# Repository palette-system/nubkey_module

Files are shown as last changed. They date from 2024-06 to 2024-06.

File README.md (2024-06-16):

# nubkey_module
Nubkey をPIM447と同じ通信で使用できるようにしたモジュールです。

<br><br>

<table>
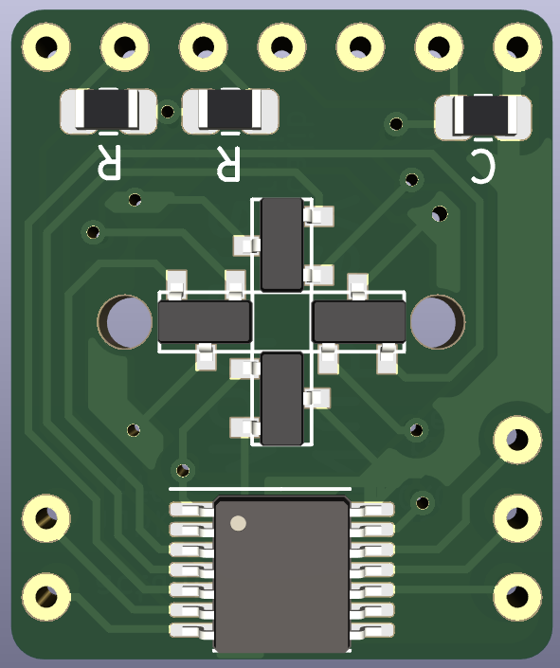
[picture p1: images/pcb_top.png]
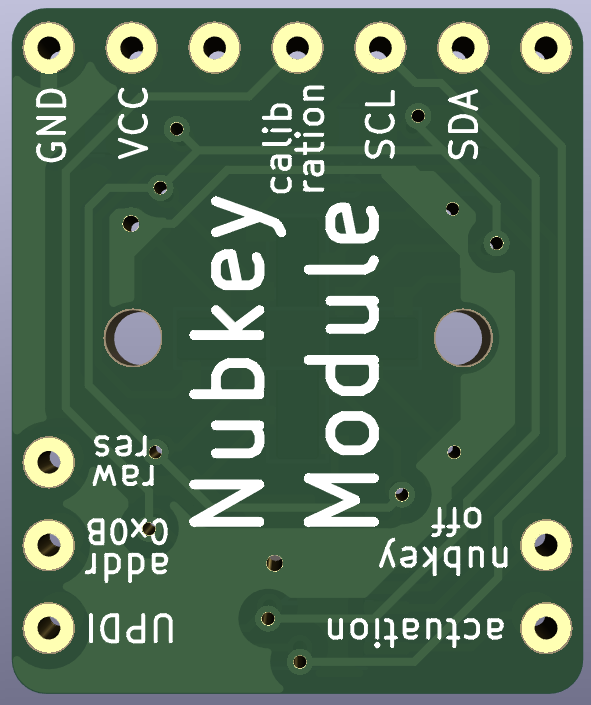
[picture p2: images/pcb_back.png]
<tr><td></td><td></td></tr>
</table>

<br><br>

## ドキュメント

<a href="/docs/structure.md">nubkey_module　基礎知識</a><br>
nubkey_modul を使用するにあたり作成者も、設計者も一度確認してからご使用ください。<br>
<br>

<a href="/docs/module_build.md">nubkey_module　はんだ付け手順</a><br>
nubkey_module をPCBにはんだ付けする際にご確認下さい。<br>
<br>

<a href="/docs/tester_build.md">nubkey_module tester　ビルドガイド</a><br>
nubkey_module tester を組み立てる際にご確認下さい。<br>
<br>

<a href="https://palette-system.github.io/nubkey_module/">nubkey_module tester　ファームウェア書き込み</a><br>
nubkey_module tester を使用する際にご確認下さい。<br>
<br>

<a href="/docs/command.md">nubkey_module　通信仕様</a><br>
nubkey_module で実行できるI2Cのコマンドの仕様書です。QMK等から速度調節する場合等にご確認下さい。<br>
<br>

<a href="/hardware/nubkey_module_tester/">nubkey_module tester　KiCadデータ</a><br>
nubkey_module tester のKiCadデータです。nubkey_module を使用したキーボードを作る際の参考にして下さい。<br>
<br>
<br>

## 基本的な接続
<br>
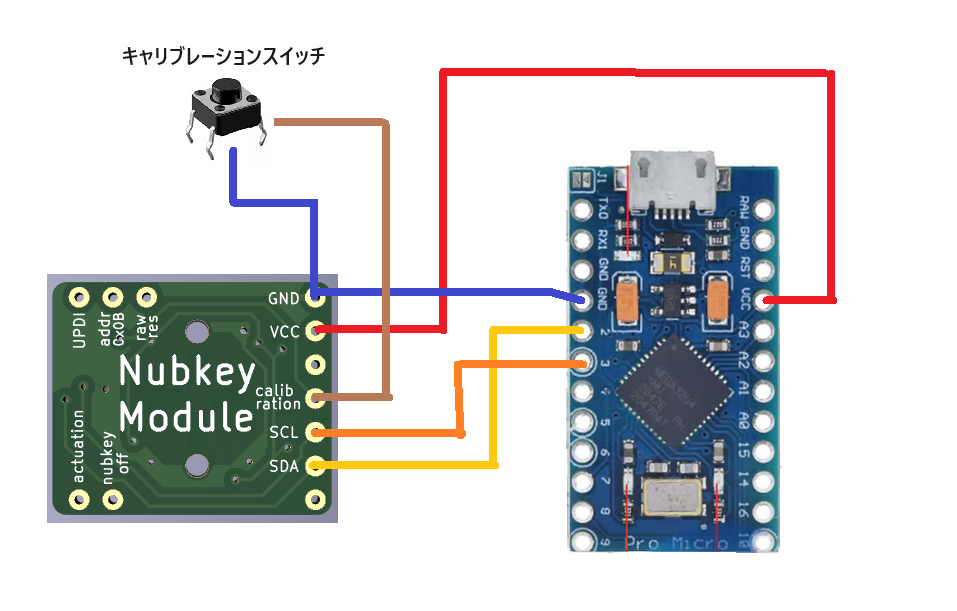
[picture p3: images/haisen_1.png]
<br>
<br>

## キャリブレーション
どんなに気を付けて作成しても組み立て毎に磁気スイッチの中心位置が0.数ミリズレが生じます。<br>
キャリブレーションスイッチを押したまま、Nubkeyを押下して上下左右にグリグリ動かす事で nubkey_module のソフト側で中心位置を調節できます。<br>
<br>

## オススメの構造
<br>
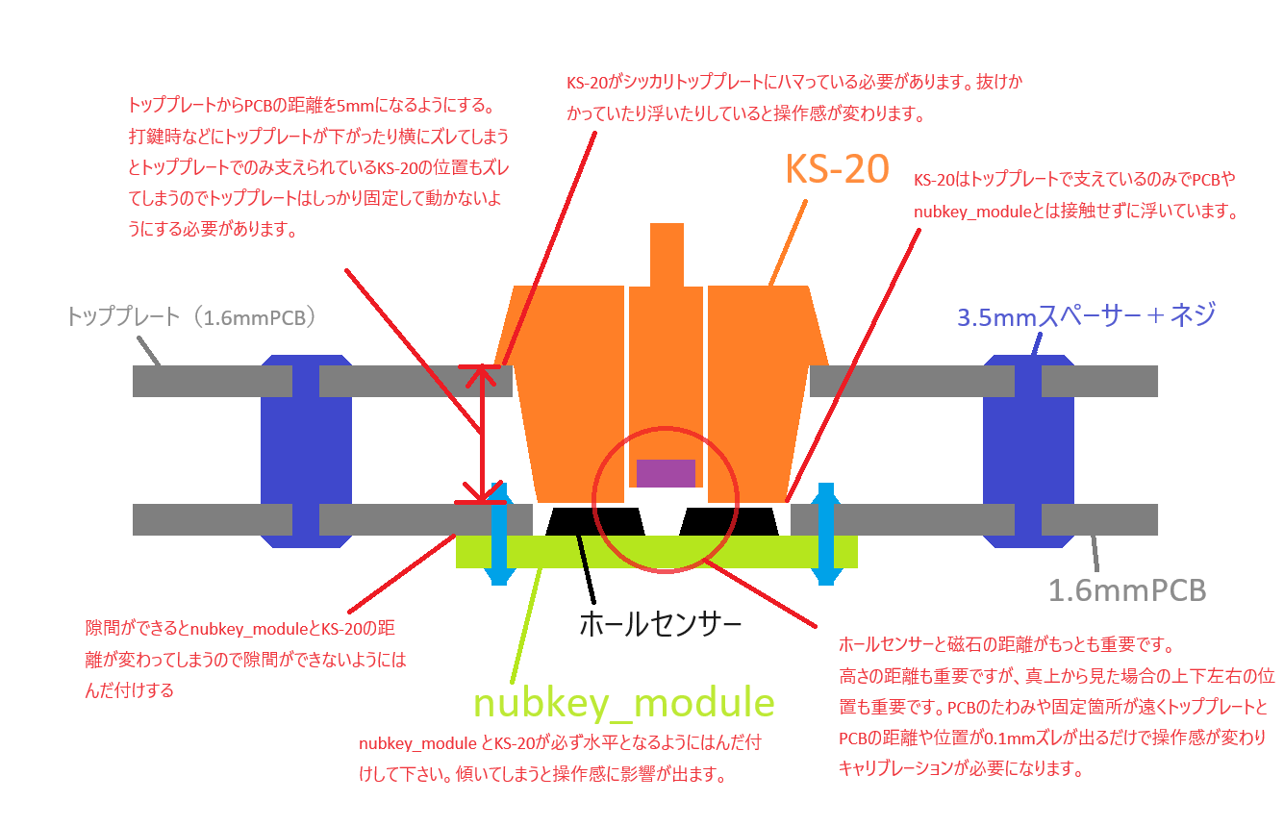
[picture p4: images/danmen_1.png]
<br>
<br>

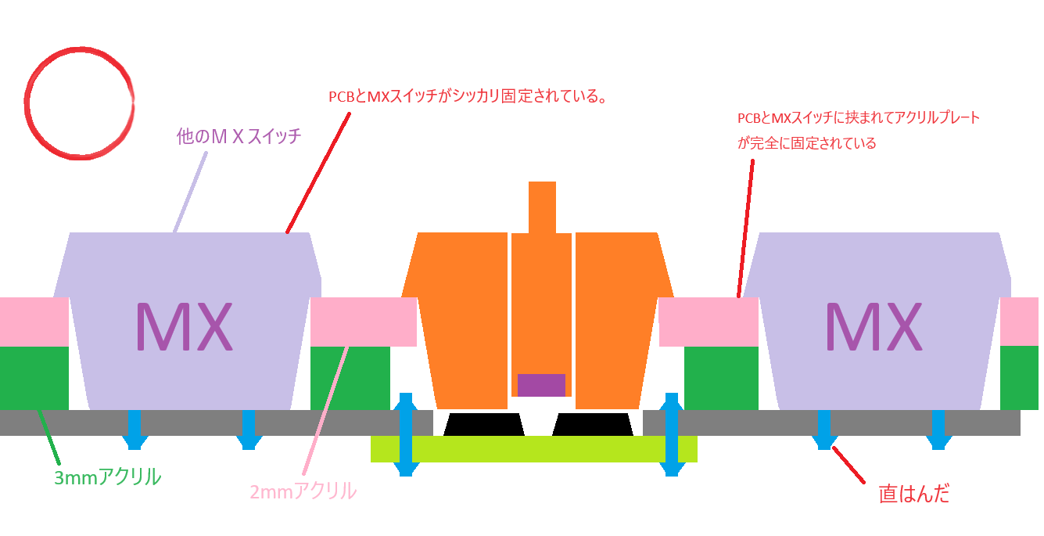
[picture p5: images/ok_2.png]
<br>
<br>

## ピンの説明

|  ピン  |  説明  |
|  ----  |  :---  |
|  UPDI  |  nubkey_module のファームを更新するためのピンです  |
|  addr 0x0B  |  nubkey_module のI2Cアドレスを0x0Bにするピンです。<br>このピンをGNDに接続した状態で起動するとI2Cアドレスが0x0Bになります。  |
|  raw res  |  I2CのレスポンスがデフォルトではPIM447互換ですがこのピンをGNDに接続すると「short X座標, short Y座標, short スイッチの押し込み具合」を返すようになります。  |
|  actuation  |  アクチュエーションポイント設定ピンです。このピンをGNDに接続するとアクチュエーション設定モードに入ります。その後GNDへの接続を切断したタイミングのKS-20のスイッチの高さがアクチュエーションポイントとしてnubkey_moduleに保存されます。  |
|  nubkey off  |  このピンをGNDに接続すると、マウス移動が無しの状態になりスイッチのON/OFFのみが変わるようになります。この時actuationピンで設定したスイッチの高さでON/OFFが切り替わります。  |
|  GND  |  GNDです  |
|  VCC  |  電源です。3.3Vを接続して下さい。  |
|  SCL  |  I2C通信用（SCL）  |
|  SDA  |  I2C通信用（SDA）  |
|  calibration  |  キャリブレーションピンです。このピンをGNDに接続した状態でKS-20のスイッチを押してグリグリすると、Nubkeyの中心位置を調節できます。<br>キャリブレーションの結果は nubkey_module に保存されるので起動のたびキャリブレーションを行う必要はありません。  |

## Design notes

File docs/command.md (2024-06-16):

# nubkey_module　通信仕様

<br>
nubkey_module は AZ1UBALL 同様にPIM447と同じ通信でQMKなどから使用できます。<br>

<br><br>

## デフォルトのレスポンスフォーマット　(PIM447互換)
<br>

|  内容  |  説明  |  サイズ(byte)  |
|  --  |  --  |  --  |
|  移動距離  |  左方向への移動距離  |  1  |
|  移動距離  |  右方向への移動距離  |  1  |
|  移動距離  |  上方向への移動距離  |  1  |
|  移動距離  |  下方向への移動距離  |  1  |
|  スイッチ  |  0x00 = ボタン OFF<br>0x80 = ボタン ON  |  1  |

<br><br>

## QMK起動時にコマンドを実行する例
<br>
通常のレスポンスとは別にI2Cでコマンドを送信する事で細かい設定を行う事ができます。<br>
<br>

```
void pointing_device_init_kb(void) {
    // _delay_ms(100); // nubkey_module の起動よりもProMicroの起動のが早い場合用 nubkey_module の起動を待ってから設定コマンドを投げる
    uint8_t res[8];
    uint16_t timeout=100;
    i2c_status_t status;
    uint8_t addr=0x0A << 1;
    // 送信するコマンド
    uint8_t cmd[]={0x48,   /* 左 */ 0x03, 0xE8,   /* 右 */ 0x03, 0xE8,   /* 上 */ 0x03, 0xE8,   /* 下 */ 0x03, 0xE8}; // マウス移動の速度 左右上下
    // uint8_t cmd[]={0x47, 0x01, 0x68}; // 高さ調節
    // uint8_t cmd[]={0x4A}; // 設定リセット
    // コマンドの送信
    status  = i2c_transmit(addr, cmd, sizeof(cmd), timeout);
    if (status != 0) return;
    status = i2c_receive(addr, res, 1, timeout);
}
```

<br><br>

# I2C コマンド一覧

## 0x60　製品の情報取得

<b>■ 送信 ： 1 byte </b>
|  内容  |  説明  |  サイズ(byte)  |
|  --  |  --  |  --  |
|  コマンドタイプ  |  0x60 (固定)  |  1  |

<b>■ レスポンス ： 4 byte </b>
|  内容  |  説明  |  サイズ(byte)  |
|  --  |  --  |  --  |
|  コマンドのエコー  |  0x60（固定）  |  1  |
|  I2Cアドレス  |  nubkey_moduleのI2Cアドレス  |  1  |
|  製品番号  |  nubkey_moduleの識別番号（0x20 固定）  |  1  |
|  ファームウェアバージョン  |  使用されているファームウェアのバージョン  |  1  |

<br><br>

## 0x40　I2Cアドレスを変更する
nubkey_moduleのI2Cアドレスを変更して、nubkey_moduleを再起動します。<br>
<b>■ 送信 ： 2 byte </b>
|  内容  |  説明  |  サイズ(byte)  |
|  --  |  --  |  --  |
|  コマンドタイプ  |  0x40 (固定)  |  1  |
|  I2Cアドレス  |  変更後のI2Cアドレス<br>0x00 を指定した場合デフォルトの0x0A（0x0BピンがGNDに接続されていた場合0x0B）になります。<br>（デフォルト：　0x00）  |  1  |

<b>■ レスポンス ： 1 byte </b>
|  内容  |  説明  |  サイズ(byte)  |
|  --  |  --  |  --  |
|  コマンドのエコー  |  0x40（固定）  |  1  |

<br><br>

## 0x41　設定内容を取得する

<b>■ 送信 ： 1 byte </b>
|  内容  |  説明  |  サイズ(byte)  |
|  --  |  --  |  --  |
|  コマンドタイプ  |  0x41 (固定)  |  1  |

<b>■ レスポンス ： 23 byte </b>
|  内容  |  説明  |  サイズ(byte)  |
|  --  |  --  |  --  |
|  コマンドのエコー  |  0x41  |  1  |
|  I2Cアドレス  |  nubkey_moduleのI2Cアドレス  |  1  |
|  nubkey_off_status  |  Nubkey_offにするかどうか<br>(0=Nubkey OFF / 1=Nubkey ON / 2=ピンの情報優先)  |  1  |
|  key_actuation  |  Nubkey_off時のアクチュエーションポイント  |  2  |
|  nub_start_time  |  Nubkeyとしてマウス操作させるまでの時間(ミリ秒)  |  2  |
|  nub_start_down  |  Nubkey マウス移動開始させるアクチュエーションポイント  |  2  |
|  nub_speed_left  |  Nubkey マウス移動させる速度 左  |  2  |
|  nub_speed_right  |  Nubkey マウス移動させる速度 右  |  2  |
|  nub_speed_up  |  Nubkey マウス移動させる速度 上  |  2  |
|  nub_speed_down  |  Nubkey マウス移動させる速度 下  |  2  |
|  rang_x  |  キャリブレーション中心の X 座標  |  2  |
|  rang_y  |  キャリブレーション中心の Y 座標  |  2  |
|  loop_delay  |  入力読み込みサイクルのdelay値(ミリ秒)  |  2  |

<br><br>

## 0x42　Nubkey OFF モードの設定
Nubkey OFF モードを設定して EEPROM に保存します。<br>
<b>■ 送信 ： 2 byte </b>
|  内容  |  説明  |  サイズ(byte)  |
|  --  |  --  |  --  |
|  コマンドタイプ  |  0x42 (固定)  |  1  |
|  モード  |  0=NubkeyOFFモード OFF<br>1=NubkeyOFFモード ON<br>2=ピンの情報優先（デフォルト）  |  1  |

<b>■ レスポンス ： 1 byte </b>
|  内容  |  説明  |  サイズ(byte)  |
|  --  |  --  |  --  |
|  コマンドのエコー  |  0x42  |  1  |

<br><br>

## 0x43　アクチュエーション設定モードの設定
アクチュエーション設定モードの設定。<br>
このコマンドを投げるのとactuationピンをGNDに接続するのと同等の制御ができます。<br>
<b>■ 送信 ： 2 byte </b>
|  内容  |  説明  |  サイズ(byte)  |
|  --  |  --  |  --  |
|  コマンドタイプ  |  0x43 (固定)  |  1  |
|  モード  |  0=アクチュエーション設定モード OFF<br>1=アクチュエーション設定モード ON<br>2=ピンの情報優先(デフォルト)  |  1  |

<b>■ レスポンス ： 1 byte </b>
|  内容  |  説明  |  サイズ(byte)  |
|  --  |  --  |  --  |
|  コマンドのエコー  |  0x43  |  1  |

<br><br>

## 0x44　キャリブレーション設定モードの設定
キャリブレーション設定モードの設定。<br>
このコマンドを投げるのとcalibrationピンをGNDに接続するのと同等の制御ができます。<br>
<b>■ 送信 ： 2 byte </b>
|  内容  |  説明  |  サイズ(byte)  |
|  --  |  --  |  --  |
|  コマンドタイプ  |  0x44 (固定)  |  1  |
|  モード  |  0=キャリブレーション設定モード OFF<br>1=キャリブレーション設定モード ON<br>2=ピンの情報優先(デフォルト)  |  1  |

<b>■ レスポンス ： 1 byte </b>
|  内容  |  説明  |  サイズ(byte)  |
|  --  |  --  |  --  |
|  コマンドのエコー  |  0x44  |  1  |

<br><br>

## 0x45　アクチュエーションポイント設定
アクチュエーションポイント設定してEEPROMに保存します。<br>
※ このアクチュエーションポイントは Nubkey OFF モードの時に使用されます。<br>
<b>■ 送信 ： 3 byte </b>
|  内容  |  説明  |  サイズ(byte)  |
|  --  |  --  |  --  |
|  コマンドタイプ  |  0x45 (固定)  |  1  |
|  アクチュエーションポイント  |  キーをONにする高さを指定<br>ここで指定した高さを下回るとキーがONになります。<br>（デフォルト：　280）  |  2  |

<b>■ レスポンス ： 1 byte </b>
|  内容  |  説明  |  サイズ(byte)  |
|  --  |  --  |  --  |
|  コマンドのエコー  |  0x45  |  1  |

<br><br>

## 0x46　Nubkey 開始までの時間を設定
Nubkeyとしてマウス操作させるまでの時間を更新してEEPROMに保存します。<br>
ここで指定した時間より短い時間でキーを離すと、タップ判定となりキーONが送信されます。<br>
<b>■ 送信 ： 2 byte </b>
|  内容  |  説明  |  サイズ(byte)  |
|  --  |  --  |  --  |
|  コマンドタイプ  |  0x46 (固定)  |  1  |
|  時間  |  Nubkey 開始までの時間（ミリ秒）（デフォルト：　200）  |  2  |

<b>■ レスポンス ： 1 byte </b>
|  内容  |  説明  |  サイズ(byte)  |
|  --  |  --  |  --  |
|  コマンドのエコー  |  0x46  |  1  |

<br><br>

## 0x47　Nubkey を動かし始める高さを設定
Nubkey 動かし始める高さを変更してEEPROMに保存します。<br>
<b>■ 送信 ： 3 byte </b>
|  内容  |  説明  |  サイズ(byte)  |
|  --  |  --  |  --  |
|  コマンドタイプ  |  0x47 (固定)  |  1  |
|  高さ  |  200～400　（デフォルト：　360）  |  2  |

<b>■ レスポンス ： 1 byte </b>
|  内容  |  説明  |  サイズ(byte)  |
|  --  |  --  |  --  |
|  コマンドのエコー  |  0x47  |  1  |

<br><br>

## 0x48　Nubkey マウス移動の速度設定
Nubkeyとしてマウス操作させる速度を更新してEEPROMに保存します。<br>
数値が小さいほど早く動きます。<br>
<b>■ 送信 ： 9 byte </b>
|  内容  |  説明  |  サイズ(byte)  |
|  --  |  --  |  --  |
|  コマンドタイプ  |  0x48 (固定)  |  1  |
|  移動速度 左  |  移動速度　(デフォルト：　800)  |  2  |
|  移動速度 右  |  移動速度　(デフォルト：　800)  |  2  |
|  移動速度 上  |  移動速度　(デフォルト：　600)  |  2  |
|  移動速度 下  |  移動速度　(デフォルト：　600)  |  2  |

<b>■ レスポンス ： 1 byte </b>
|  内容  |  説明  |  サイズ(byte)  |
|  --  |  --  |  --  |
|  コマンドのエコー  |  0x48  |  1  |

<br><br>

## 0x49　Nubkey 読み込みサイクルのdelay値設定
Nubkey 読み込みサイクルのdelay値を変更してEEPROMに保存します。<br>
<b>■ 送信 ： 3 byte </b>
|  内容  |  説明  |  サイズ(byte)  |
|  --  |  --  |  --  |
|  コマンドタイプ  |  0x49 (固定)  |  1  |
|  時間  |  停止する時間（ミリ秒）（デフォルト 2）  |  2  |

<b>■ レスポンス ： 1 byte </b>
|  内容  |  説明  |  サイズ(byte)  |
|  --  |  --  |  --  |
|  コマンドのエコー  |  0x49  |  1  |

<br><br>

## 0x4A　設定を全てリセットして再起動
<b>■ 送信 ： 1 byte </b>
|  内容  |  説明  |  サイズ(byte)  |
|  --  |  --  |  --  |
|  コマンドタイプ  |  0x4A (固定)  |  1  |

<b>■ レスポンス ： 1 byte </b>
|  内容  |  説明  |  サイズ(byte)  |
|  --  |  --  |  --  |
|  コマンドのエコー  |  0x4A  |  1  |

<br><br>

## 0x50　Nubkey のアナログ情報を取得
<b>■ 送信 ： 1 byte </b>
|  内容  |  説明  |  サイズ(byte)  |
|  --  |  --  |  --  |
|  コマンドタイプ  |  0x50 (固定)  |  1  |

<b>■ レスポンス ： 7 byte </b>
|  内容  |  説明  |  サイズ(byte)  |
|  --  |  --  |  --  |
|  コマンドのエコー  |  0x50  |  1  |
|  X座標  |  Nubkey の現在のX座標  |  2  |
|  Y座標  |  Nubkey の現在のY座標  |  2  |
|  高さ  |  キーの押し込み現在の高さ  |  2  |

<br><br>

## 0x51　ホールセンサーの情報を取得
<b>■ 送信 ： 1 byte </b>
|  内容  |  説明  |  サイズ(byte)  |
|  --  |  --  |  --  |
|  コマンドタイプ  |  0x51 (固定)  |  1  |

<b>■ レスポンス ： 9 byte </b>
|  内容  |  説明  |  サイズ(byte)  |
|  --  |  --  |  --  |
|  コマンドのエコー  |  0x51  |  1  |
|  アナログ値  |  ホールセンサーのアナログ値 上  |  2  |
|  アナログ値  |  ホールセンサーのアナログ値 下  |  2  |
|  アナログ値  |  ホールセンサーのアナログ値 左  |  2  |
|  アナログ値  |  ホールセンサーのアナログ値 右  |  2  |

<br><br>

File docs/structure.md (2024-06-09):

# nubkey_module　を使用する上での基礎知識
<br><br>
nubkey_module を使用したキーボードを作成する人も設計する人もどういう仕組みで動いている物なのか確認してからのご使用をお願いします。<br>
とても繊細な仕組みの元成り立っている技術なので、設計の仕方、組み立て方次第で操作感に影響が出ます。<br>
<br><br>

## 構造の説明
<br>

pcb

<br>

### KS-20とホールセンサーの位置が最も重要
KS-20の中心位置と十字に並ぶホールセンサーの中心の位置がピッタリ合っているほど操作しやすくなります。<br>
位置が0.1mmズレるだけで特定の方向にだけにマウス移動する速度が遅くなったり、ひどい場合はマウスが勝手に移動してしまうなどの現象が起こります。<br>
多少であればキャリブレーションを行う事で調節できますが、使っているウチに振動でトッププレートが沈んだり、たわみでKS-20の位置とホールセンサーの位置がズレたりすると定期的にキャリブレーションを行わなければならず不便な物になってしまいます。<br>

<br><br>

### KS-20 は浮いています
NubkeyとなるKS-20はトッププレートに支えられているのみで浮いています。<br>
通常の電気接点のあるMXスイッチであれば多少ソケットから抜けたり斜めに刺さってしまっても動作しますが、Nubkeyはマウスの操作に影響が出てしまいます。<br>
なので 「KS-20→トッププレート→PCB→nubkey_module」 までの間がシッカリ固定されて動かないようになっている必要があります。<br>

<br><br>

### nubkey_module のはんだづけ
PCBに nubkey_module をはんだ付けする際はシッカリとPCBと密着して隙間が無い状態にして下さい。<br>
ここで隙間ができるとKS-20と水平にならなくなってしまい操作感に影響が出る可能性があります。<br>

<br><br>
<br><br>

## キャリブレーションについて
<br>

### 磁石の中心位置
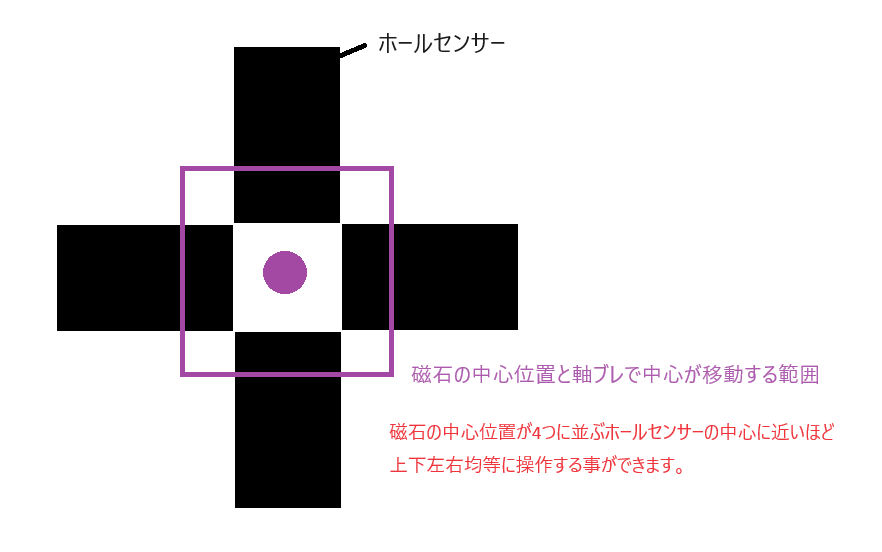
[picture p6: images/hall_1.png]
<br>
<br>
磁石の中心位置が最も磁力線が強くなっていて、この位置が上下左右に動いた事をホールセンサーで感知してマウスを上下左右に動かしています。<br>
KS-20の軸ブレで移動する範囲が丁度十字に並んだホールセンサーの中心にあるとどの方向に移動しても均一に移動を感知できるので、操作感が良くなります。<br>
<br>

### 中心位置がズレると何が起こるか
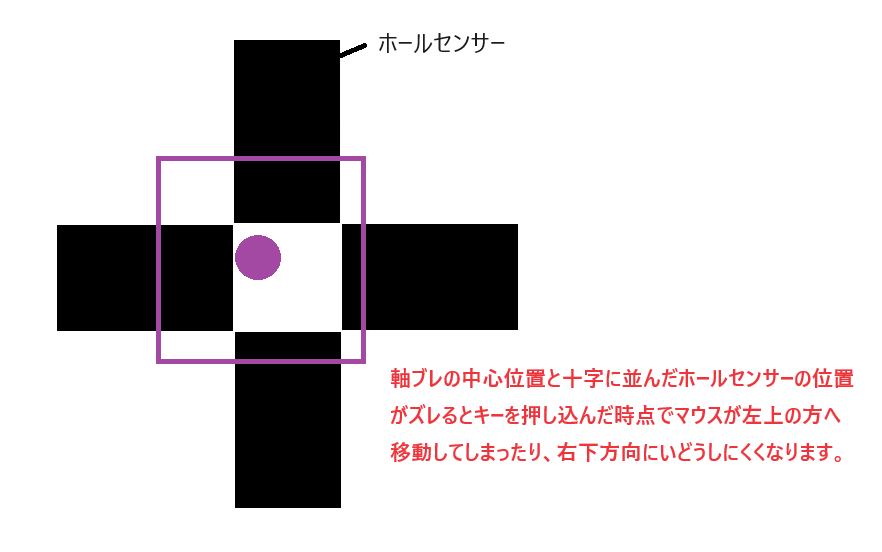
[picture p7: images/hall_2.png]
<br>
<br>
KS-20の軸ブレの中心位置がズレると、十字に並んだホールセンサー上での移動できる範囲が変わります。<br>
デフォルトのままだと十字の中心位置がNubkeyの中心と設定してあるので、キーを押しただけで左上の方へマウス移動してしまい操作感が悪くなります。<br>
<br>

### キャリブレーション
0.1mmのズレで操作感が変わってしまうので、例えばトッププレートを外してもう一度付け直しただけでネジ穴の遊び(隙間)分KS-20の中心位置が移動したりします。<br>
なのでキャリブレーションボタンを押したままKS-20をグリグリする事で、現在軸ブレはどの範囲まで移動できるかをnubkey_moduleに確認させる事ができます。<br>
そうする事で軸ブレの中心位置を設定し、マウスが特定方向にだけ動きにくくなる事を修正できます。<br>
<br>

### キャリブレーションは完璧ではない
中心位置の調整はキャリブレーションで行えるのですが、軸ブレの中心位置がズレていた場合に特定の方向のホールセンサーからの距離が遠くなってしまうと、その方向への数値の取得が小さくなります。<br>
例えば左に行く時はちょっと倒すとゆっくり動く、いっぱい倒すと早く動くの調節が利くけど、右に倒す時はちょっと倒しただけで早く動いてしまうなどの現象が起こります。<br>
nubkey_moduleに特定のI2Cコマンドを投げる事で上下左右の移動速度を設定できるようにして、ある程度は調節できるようにしてありますが都度調節はなかなか難しいので設計時、組み立てる時にnubkey_moduleやプレートにズレが発生しない様に気を付けて下さい。<br>

<br><br>
<br><br>

## トッププレートとPCBの固定方法
<br>
上記で説明してきた通りトッププレートとPCBがシッカリ固定されている事が快適にNubkeyを操作するにあたってとても重要です。<br>
固定方法について良かったパターン悪かったパターンを紹介します。<br>
まだいろいろな方法を試せていないというのが現状なのでいろいろな構造を試して頂けたらなと思います。<br>
<br>

<table>
<tr>
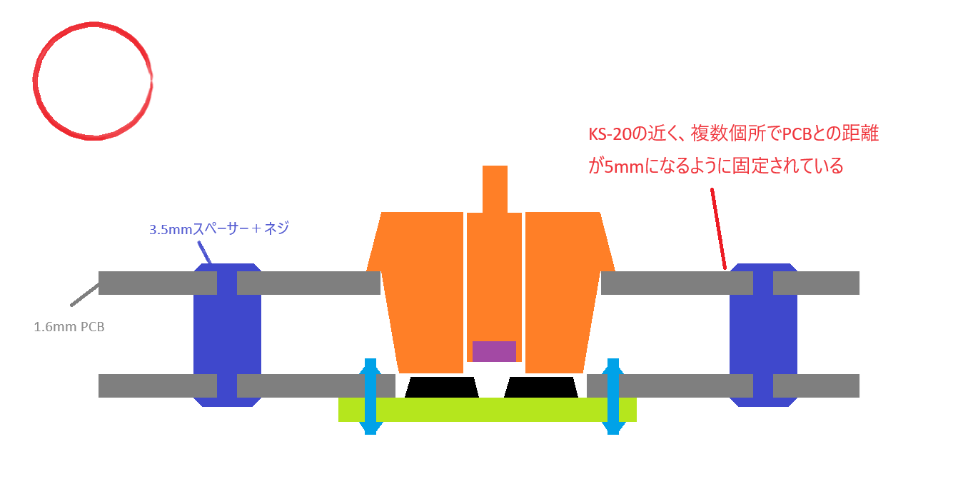
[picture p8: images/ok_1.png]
<td></td>
<td>
<b>トッププレートとPCBをスペーサーで固定する</b><br>
かなり確実なパターンで、スペーサーで固定しているのでズレが発生してもネジを外してトッププレートを付け直す事で調整できます。<br>
ただネジで止める箇所が遠かったり、止める数が少なかったりした場合他のMXスイッチのせいで高さに隙間ができたり、PCBのたわみで位置ズレ高さズレが発生する可能性があるので、Nubkeyの近く数か所で固定するのが良さそうです。<br>
長く使用した場合にネジのゆるみなどで固定が甘くならないかの心配は少しあります。
</td>
</tr>
<tr>
<td></td>
<td>
<b>2mm＋3mmトッププレートで、他のMXスイッチは直はんだ</b><br>
一番確実なパターンで、5mmのプレートを他のMXスイッチで挟んでPCBに完全に固定します。<br>
なので使用するにあたって一度位置調整すれば位置ズレが発生する事がありません。
</td>
</tr>
<tr>
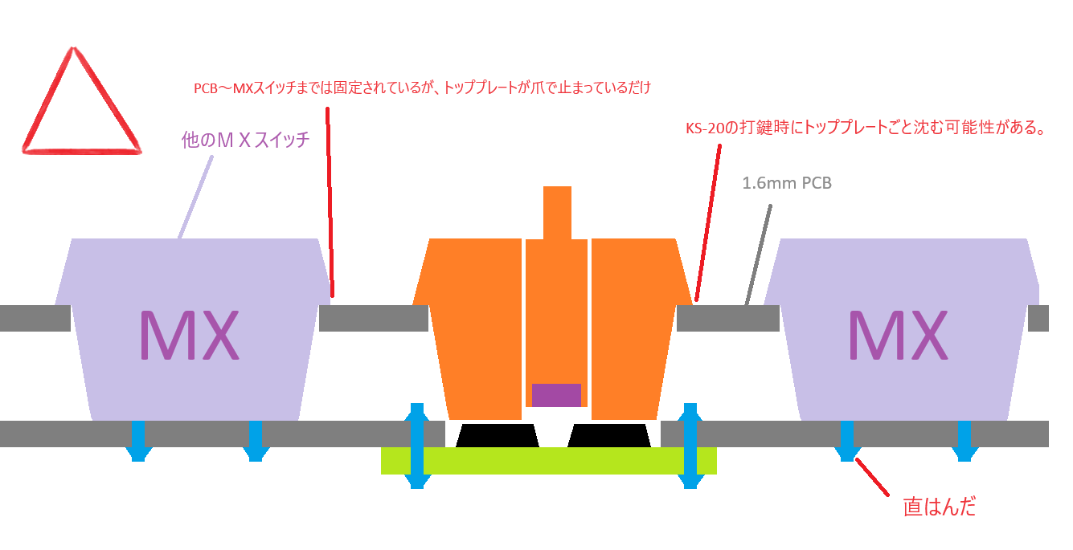
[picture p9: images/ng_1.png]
<td></td>
<td>
<b>トッププレートが浮いているパターン</b><br>
トッププレートがMXスイッチの爪で固定されているだけなので、使用している間に爪が外れやすくなったりPCBのたわみで位置ズレが発生する可能性があります。<br>
ただし全く使えないというわけでは無いので定期的にキャリブレーションや速度調整をする前提であれば一度試してみるのはありだと思います。<br>
</td>
</tr>
<tr>
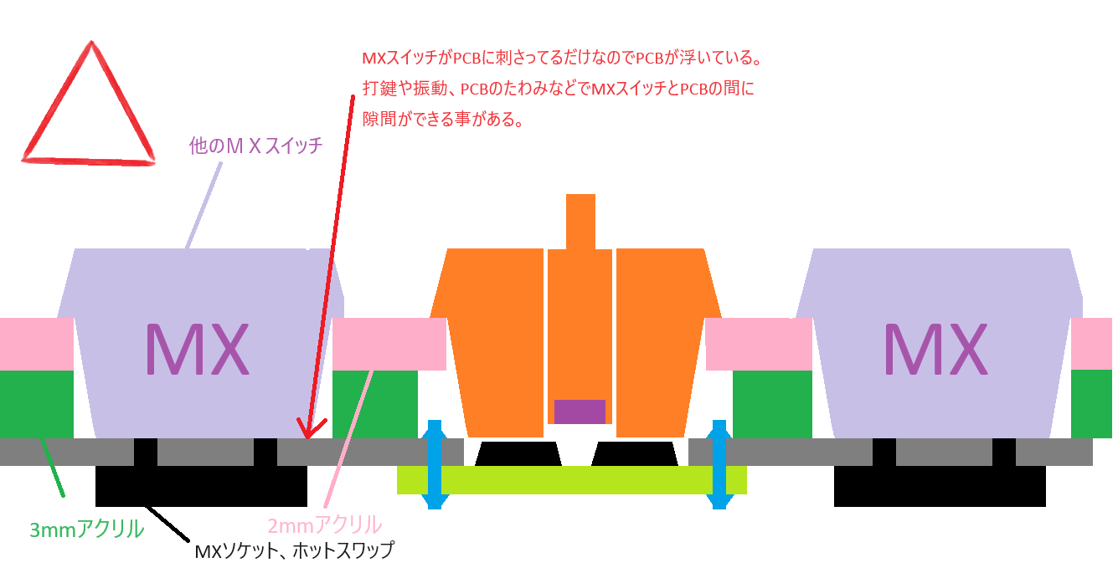
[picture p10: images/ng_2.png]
<td></td>
<td>
<b>PCBがホットスワップで支えられてるだけで浮いてる</b><br>
ホットスワップは使用しているウチに抜けたり浮いたりし易いので、この構造だと位置ズレが発生する可能性があります。<br>
どこかでトッププレートからPCBまでネジなどで固定できると良いかもしれません。（アクリルもPCBもたわみが発生するので近くで数か所が望ましいです）
</td>
</tr>
</table>

<br><br>

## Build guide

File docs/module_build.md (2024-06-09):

# nubkey_module　のはんだ付け
<br><br>
nubkey_module は PCB に隙間なくピッタリとくっついた状態ではんだ付けする必要があります。<br>
手順を確認しながらはんだ付けして下さい。<br>
<br><br>

## 細ピンヘッダをカットします
<br>
ピンに合わせて細ピンヘッダをカットしてください。<br>
<br>
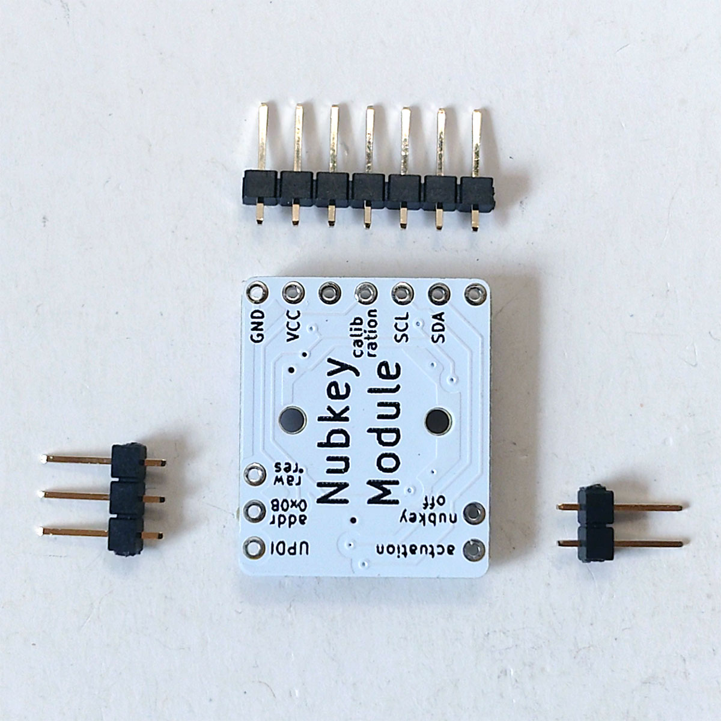
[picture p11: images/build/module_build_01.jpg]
<br>

<br><br>

## PCB の裏面に nubkey_module の乗せます
<br>
PCB の裏面に nubkey_module の乗せて細ピンヘッダを刺して下さい。<br>
<br>
<table><tr>
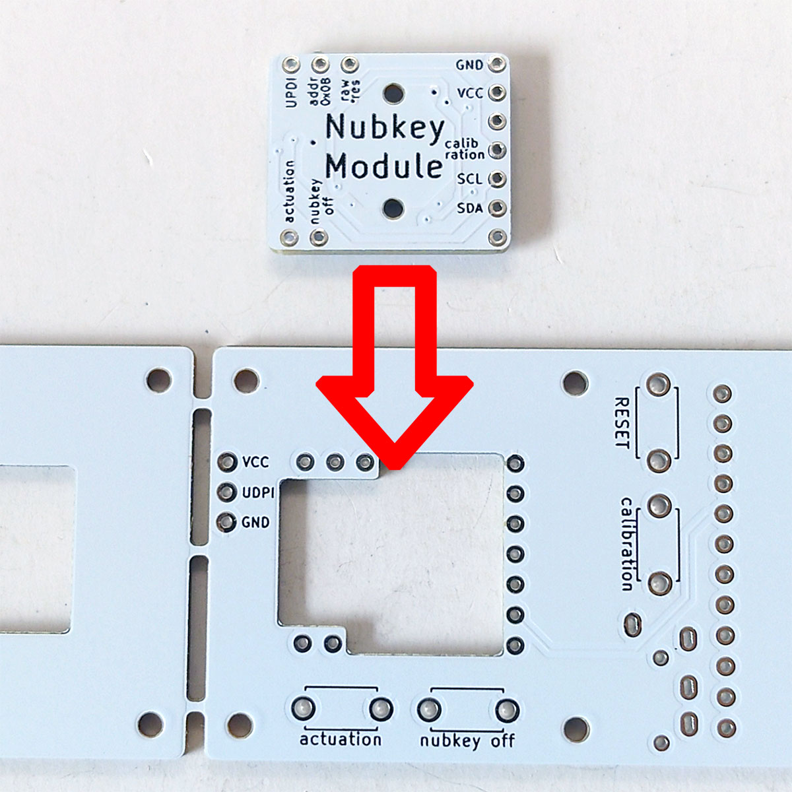
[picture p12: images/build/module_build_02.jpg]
<td></td>
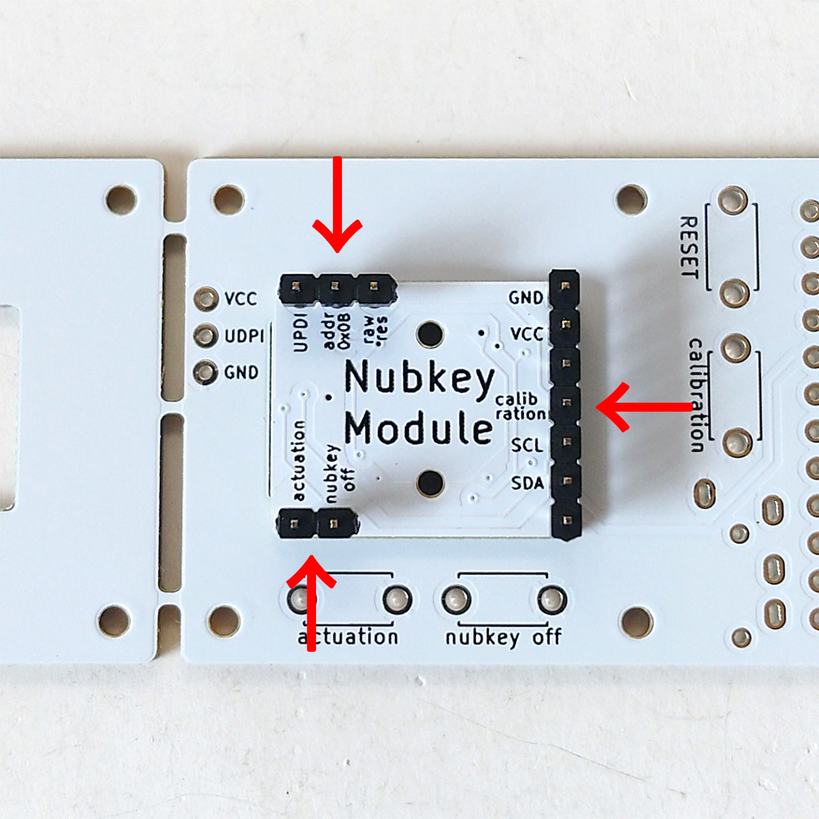
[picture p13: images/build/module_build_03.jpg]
<td></td>
</tr></table>

<br><br>

## マスキングテープで固定します
<br>
PCB を持ち上げて、PCB と nubkey_module の間に隙間ができないようにマスキングテープで固定します。<br>
<br>
<table><tr>
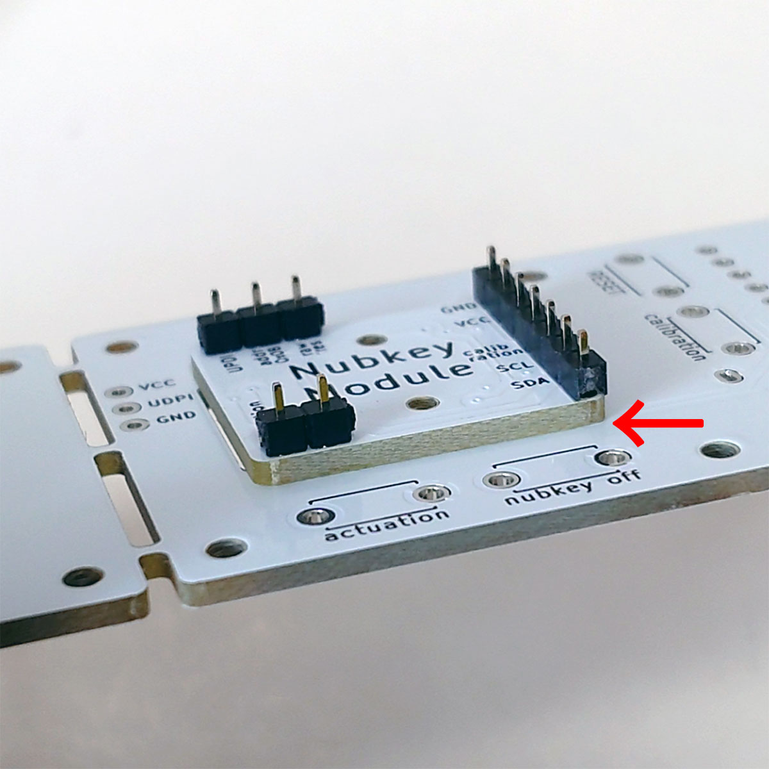
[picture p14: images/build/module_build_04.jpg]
<td></td>
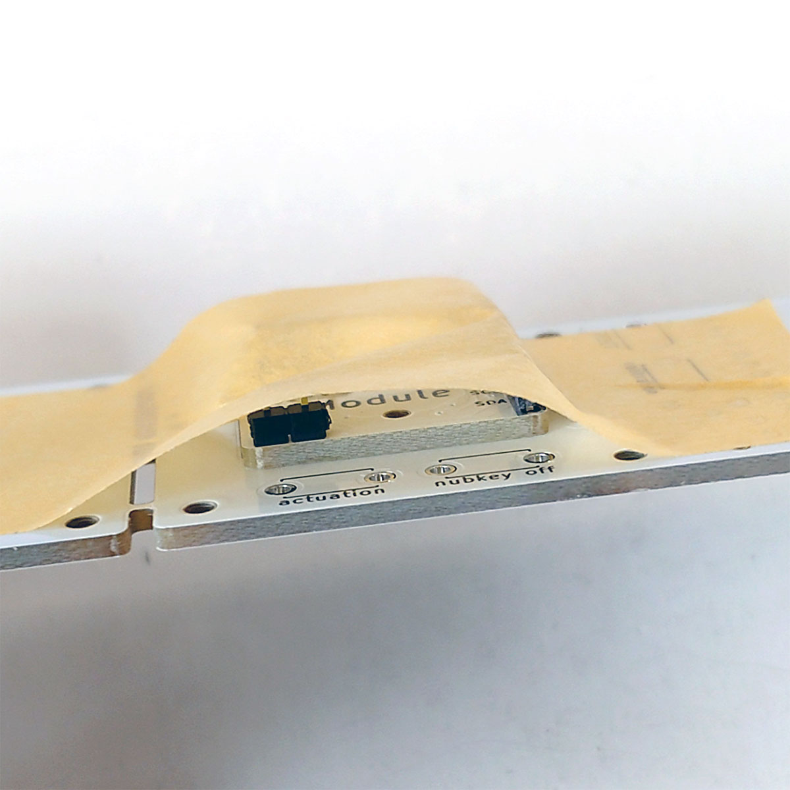
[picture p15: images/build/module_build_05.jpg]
<td></td>
</tr></table>

<br><br>

## 表面のピンをはんだ付けします
<br>
PCB を表向きに置き、ピンヘッダ部分をはんだ付けします。<br>
<br>
<table><tr>
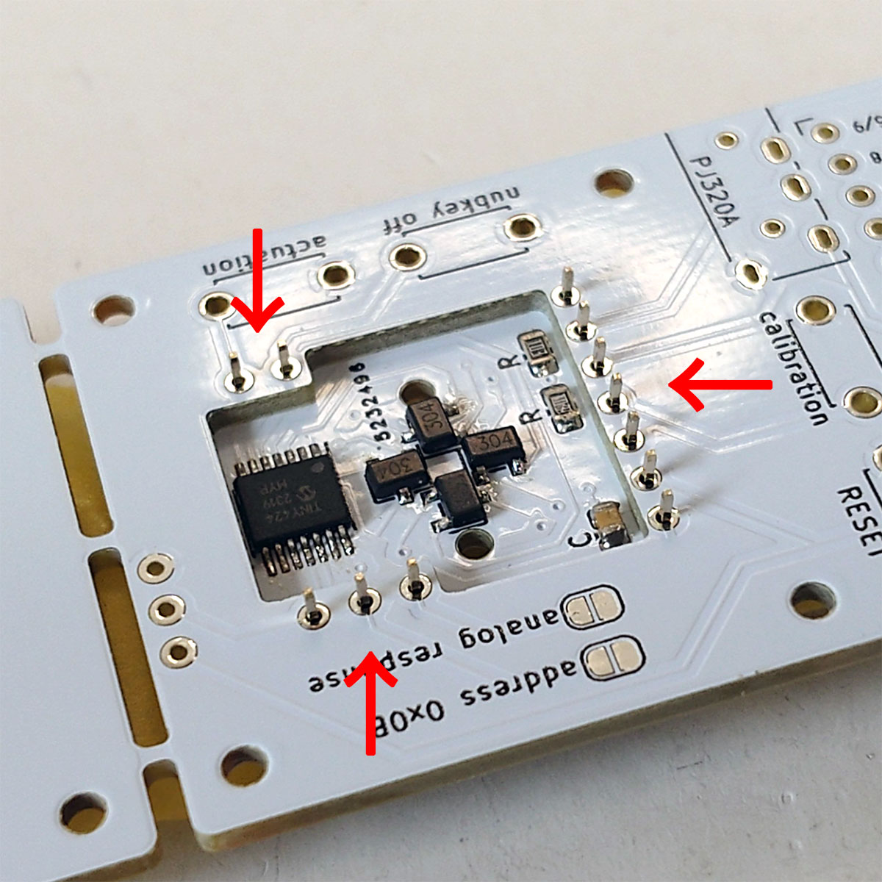
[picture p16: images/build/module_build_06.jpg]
<td></td>
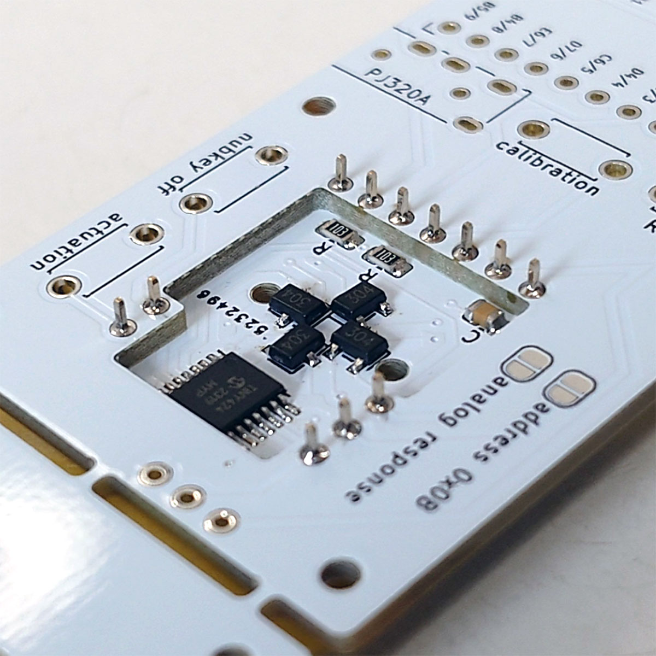
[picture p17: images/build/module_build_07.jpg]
<td></td>
</tr></table>

<br><br>

## 裏面のプラスチック部分を取り除きます
<br>
PCB を裏向きにし、マスキングテープを外します。<br>
ニッパーやピンセットを使用してプラスチック部分を引っ張るように外します。<br>
<br>
<table><tr>
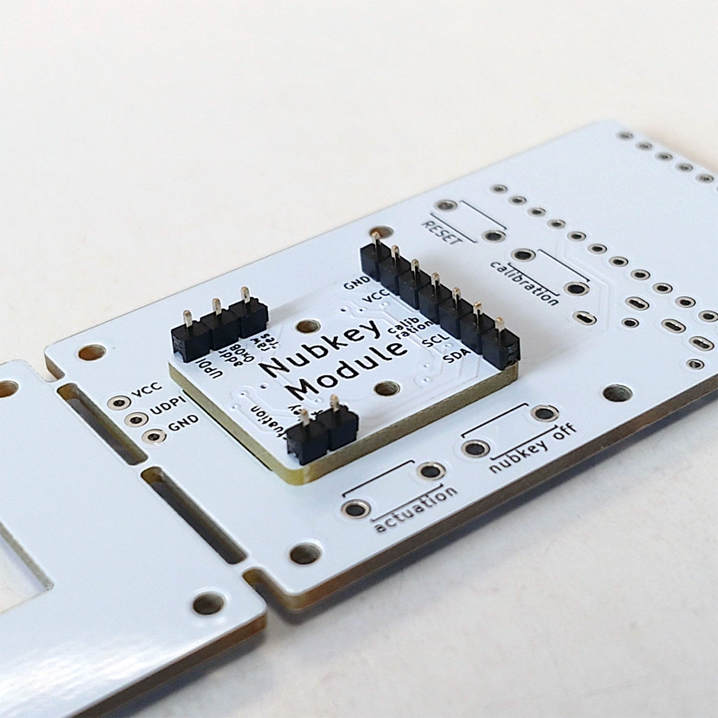
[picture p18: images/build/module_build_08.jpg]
<td></td>
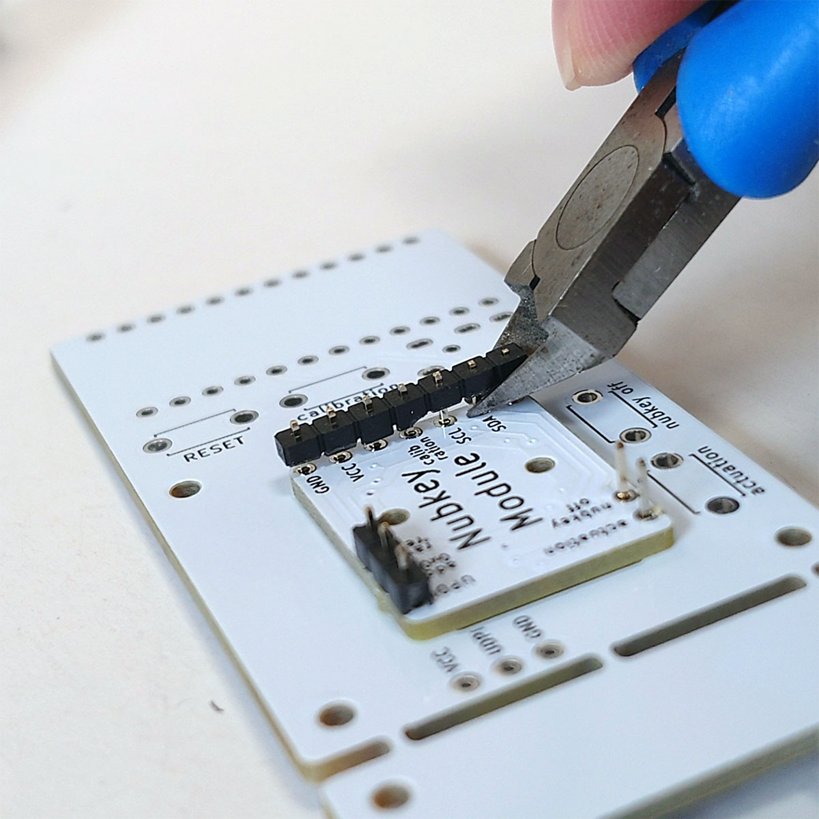
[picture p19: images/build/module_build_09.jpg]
<td></td>
</tr></table>

<br><br>

## 裏面のピンをはんだ付けします
<br>
PCB と nubkey_module に隙間ができてない事を確認しながらピンをはんだ付けします。<br>
<br>
<table><tr>
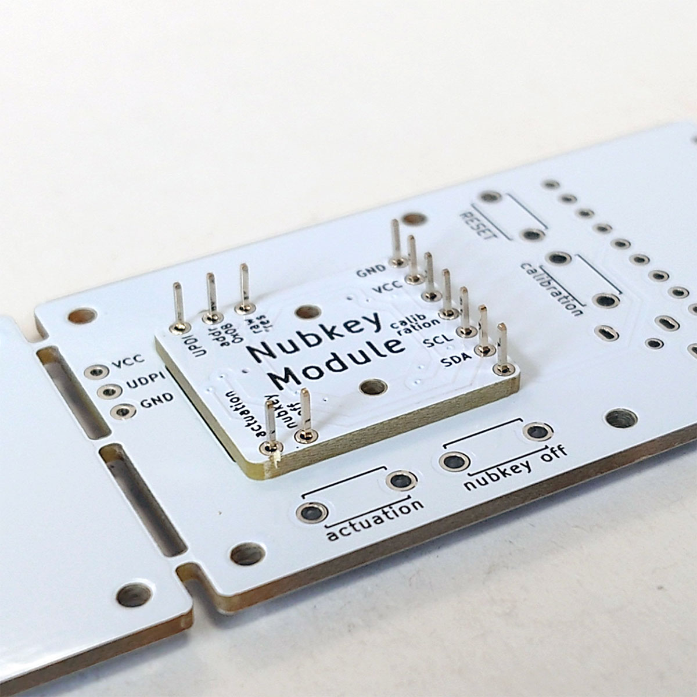
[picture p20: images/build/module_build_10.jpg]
<td></td>
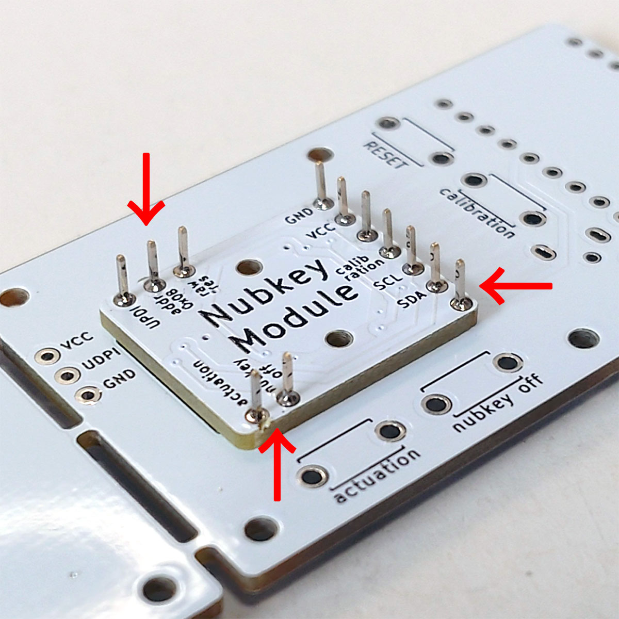
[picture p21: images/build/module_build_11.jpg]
<td></td>
</tr></table>

<br><br>

## ピンの長い部分をカットして完了です
<br>
表面、裏面共にピンヘッダが伸びている部分をニッパーでカットしで完了です。<br>
<br>
<table><tr>
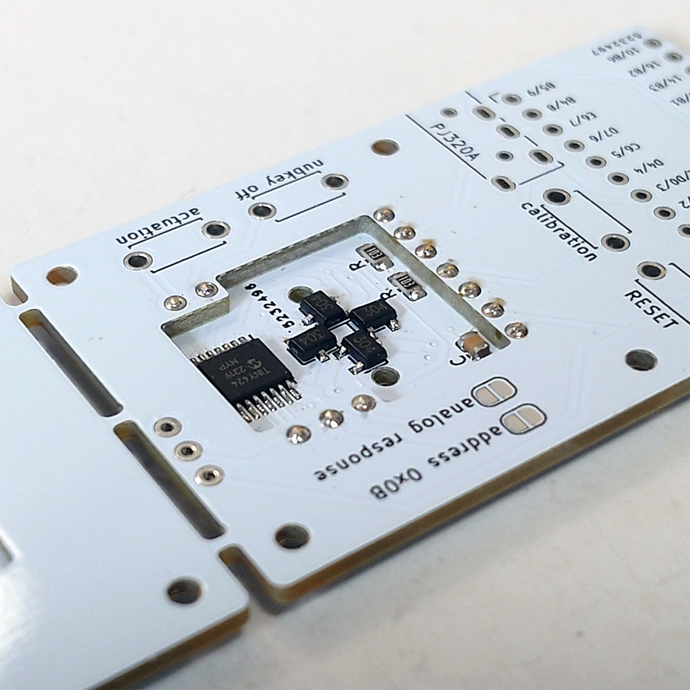
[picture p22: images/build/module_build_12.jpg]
<td></td>
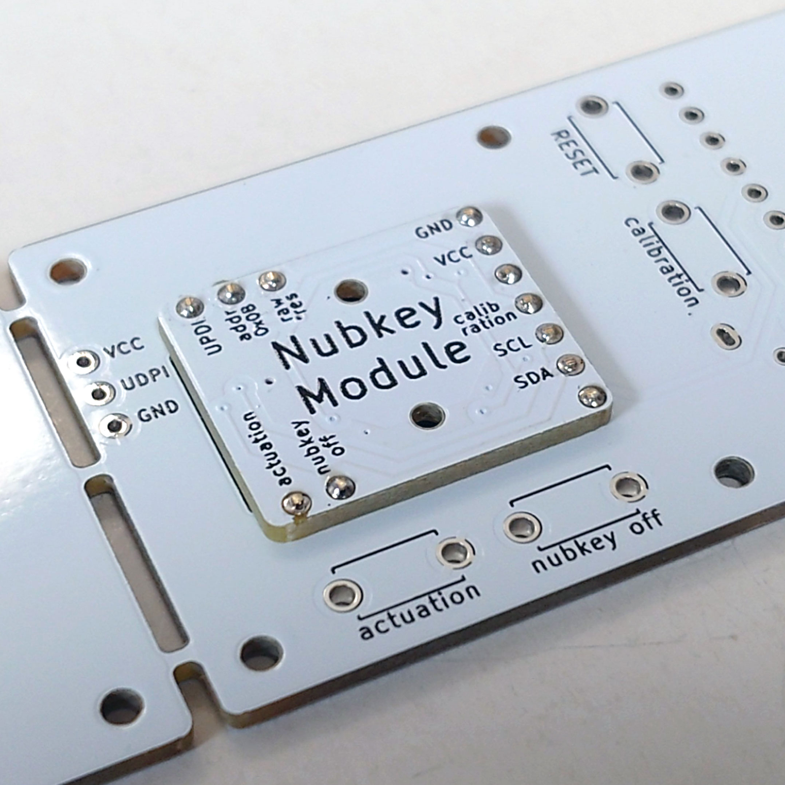
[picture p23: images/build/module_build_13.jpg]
<td></td>
</tr></table>

<br><br>

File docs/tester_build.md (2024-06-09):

# nubkey_module tester　ビルドガイド
<br><br>

## nubkey_module をPCBにはんだ付けします
<br>
下記リンク先に手順がまとめられているのでそちらを参考に nubkey_module をはんだ付けしてください。<br><br>
<a href="./module_build.md" target="_blank">nubkey_module のはんだ付け</a><br>

<br><br>

## タクトスイッチのはんだ付けします
<br>
表面から「calibration」と「RESET」の所にタクトスイッチをはんだ付けして下さい。<br>
<br>
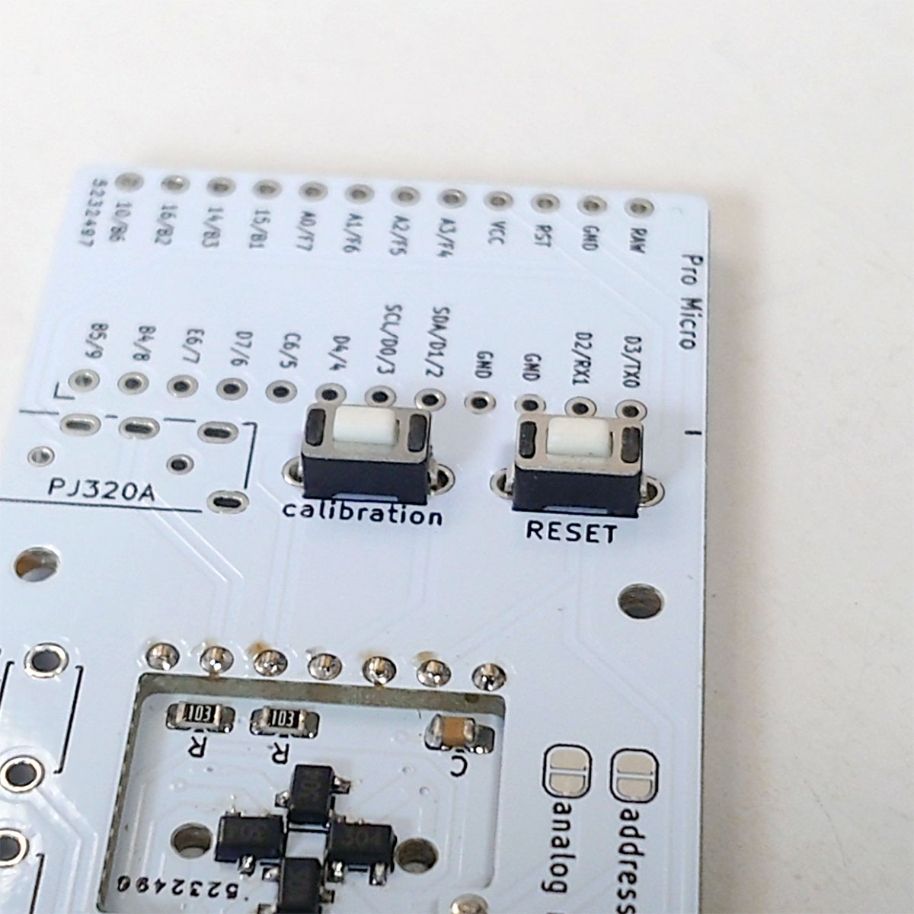
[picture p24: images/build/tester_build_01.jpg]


<br><br>

## トッププレートを切り離します
<br>
ニッパーなどを使いPCBのトッププレート部分を切り離して下さい。<br>
<br>
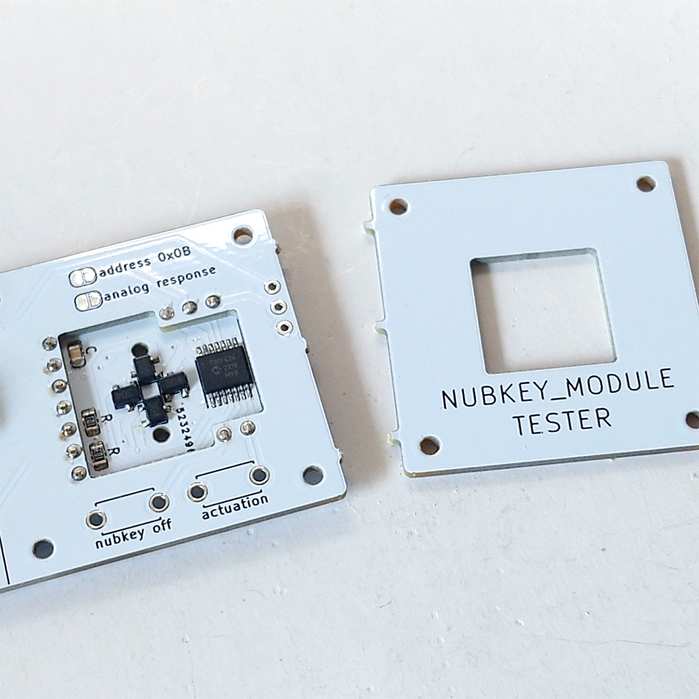
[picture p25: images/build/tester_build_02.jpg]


<br><br>

## スペーサーを固定します
<br>
PCBの裏面から4ヶ所のネジ穴にネジを通しスペーサーを固定して下さい。<br>
<br>
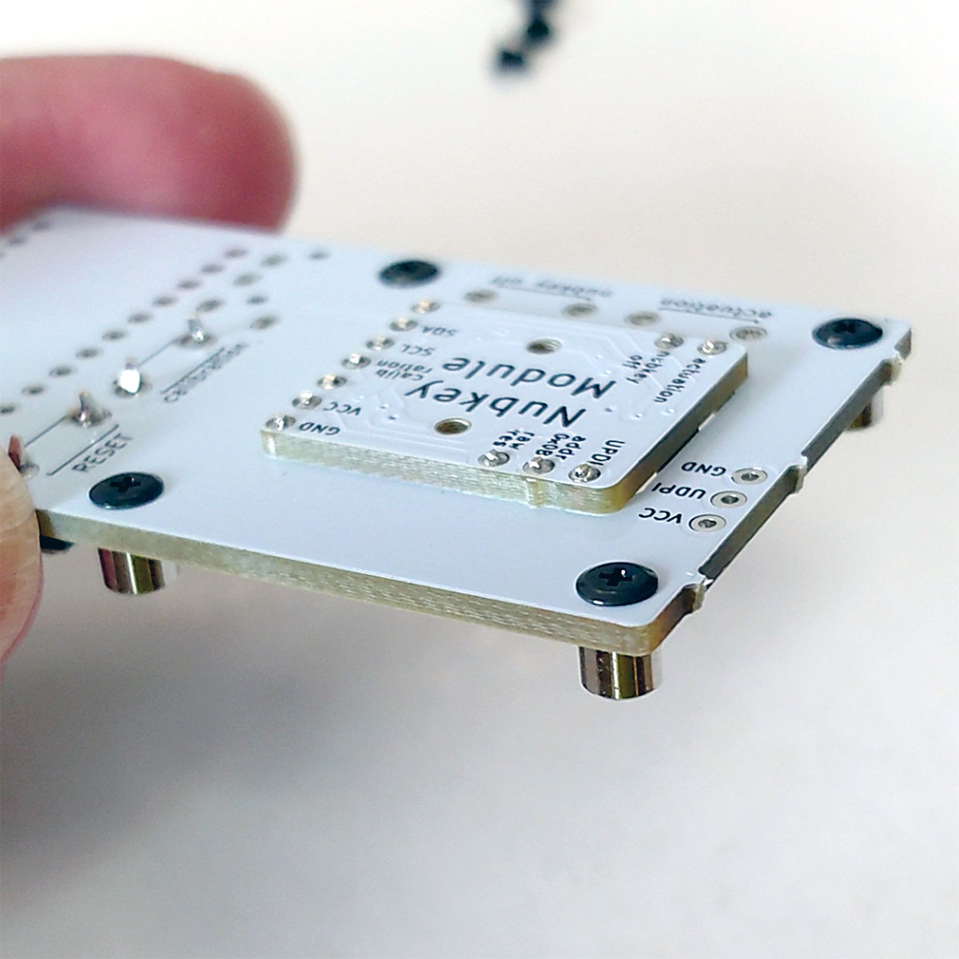
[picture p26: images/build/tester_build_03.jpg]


<br><br>

## トッププレートを固定します
<br>
表面にトッププレートを乗せ、4ヶ所のネジ穴をネジで固定して下さい。<br>
<br>
<table><tr>
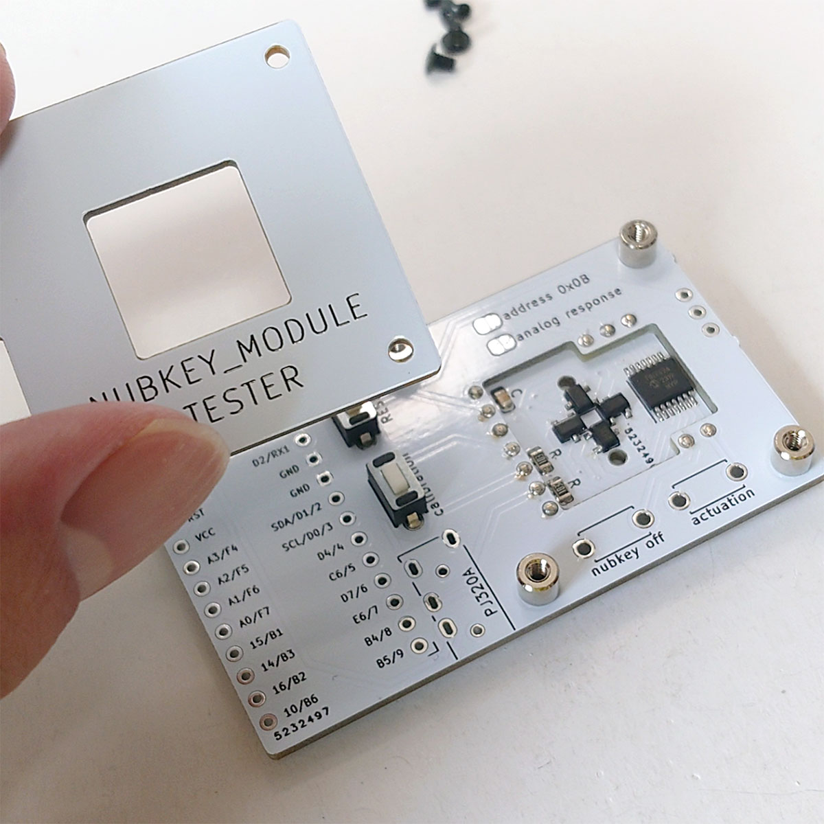
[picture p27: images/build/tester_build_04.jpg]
<td></td>
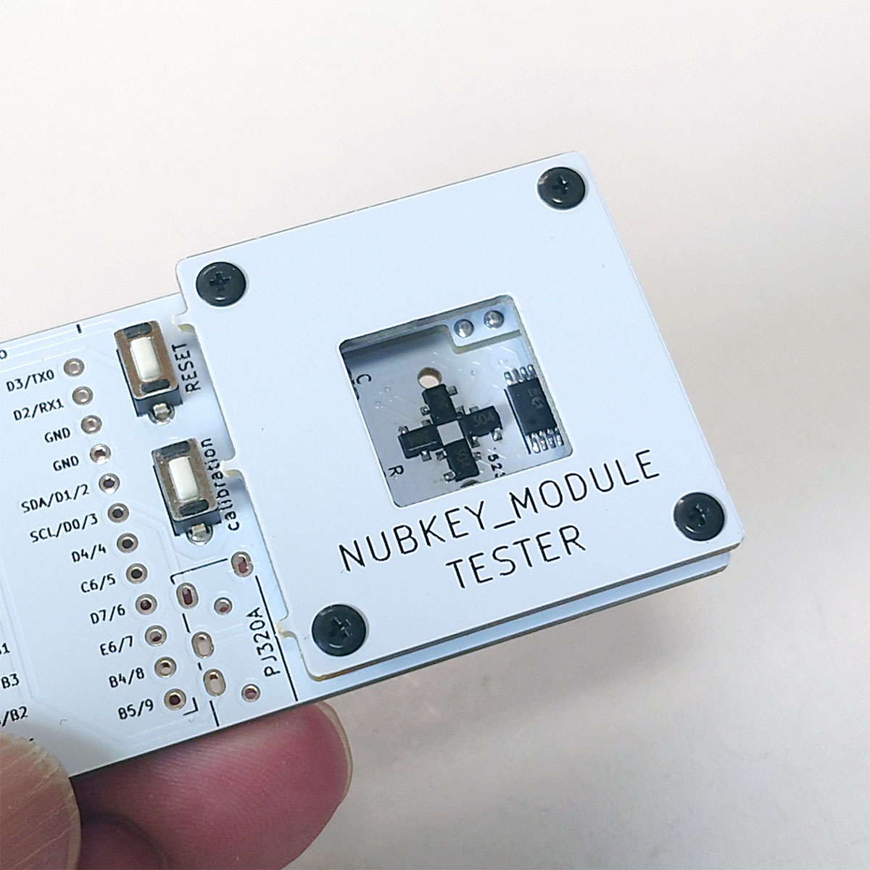
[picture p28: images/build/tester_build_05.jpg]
<td></td>
</tr></table>

<br><br>

## KS-20を差し込みます
<br>
KS-20の足を確認しながら横向きでKS-20を差し込んで下さい。<br>
<br>
<table><tr>
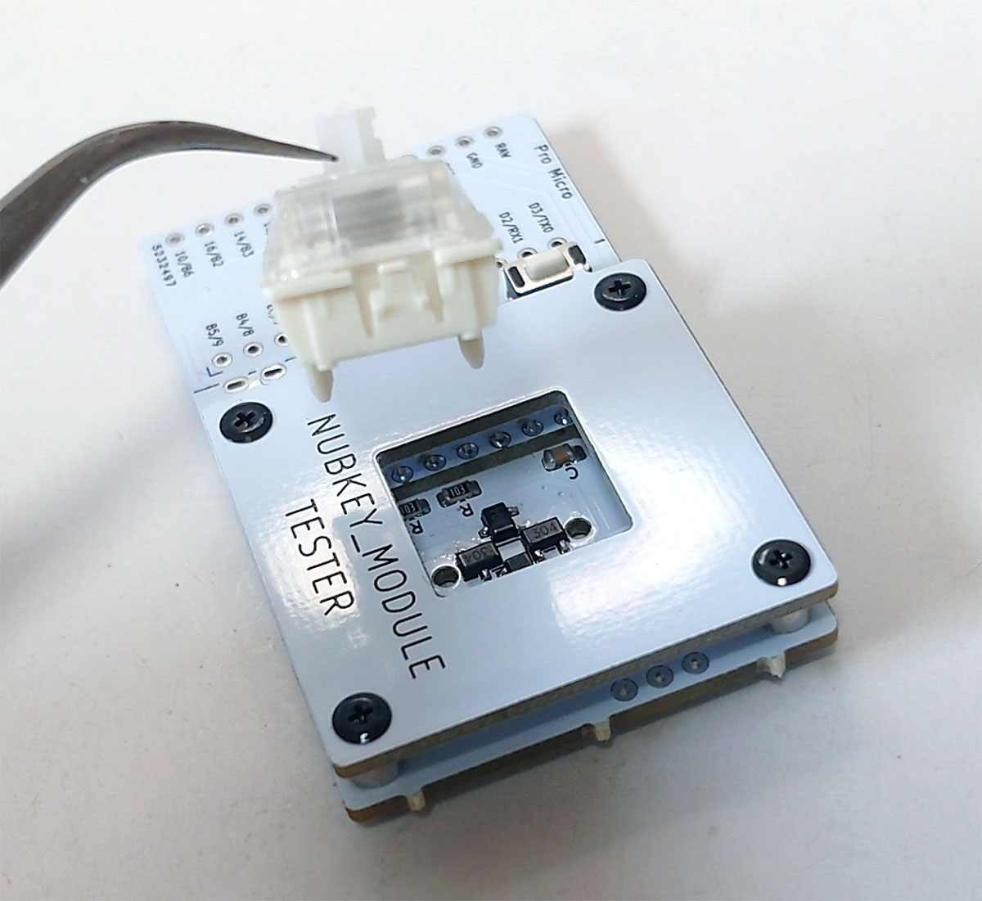
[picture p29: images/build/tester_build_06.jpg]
<td></td>
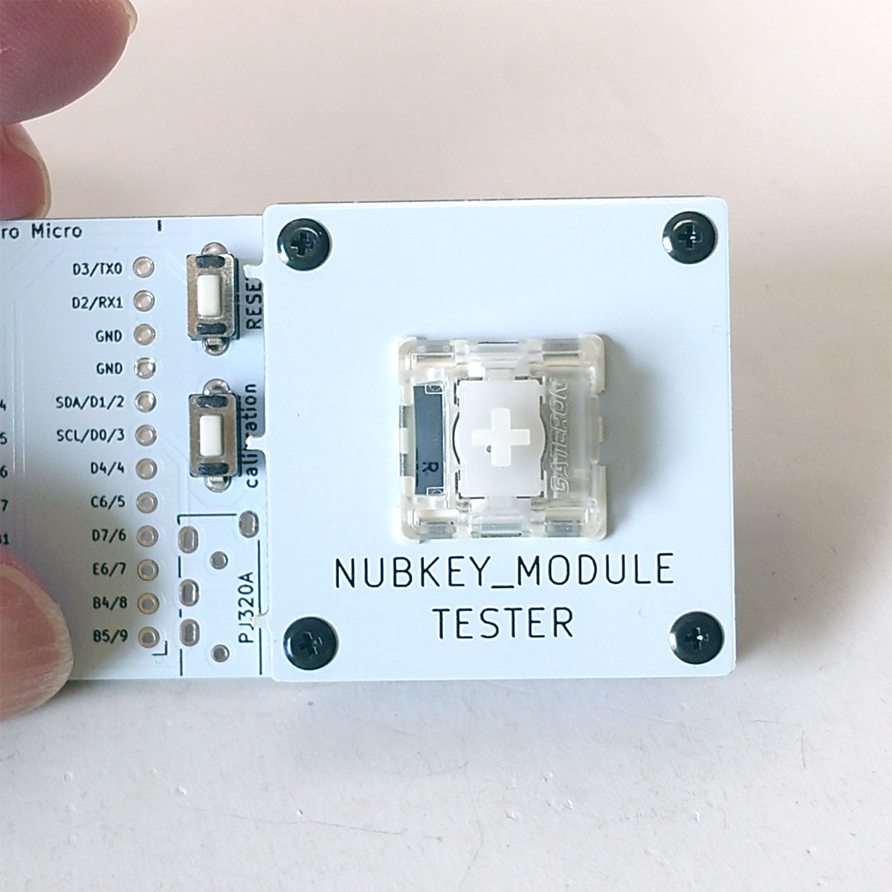
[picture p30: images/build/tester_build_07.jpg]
<td></td>
</tr></table>

<br><br>

## ProMicroをはんだ付します
<br>
ピンヘッダ、ピンソケットを使用しても良いですし、ピン穴はコンスルー対応なのでコンスルーも使用できます。<br>
向きだけ気を付けて好みの方法でProMicroをはんだ付けして下さい。<br>
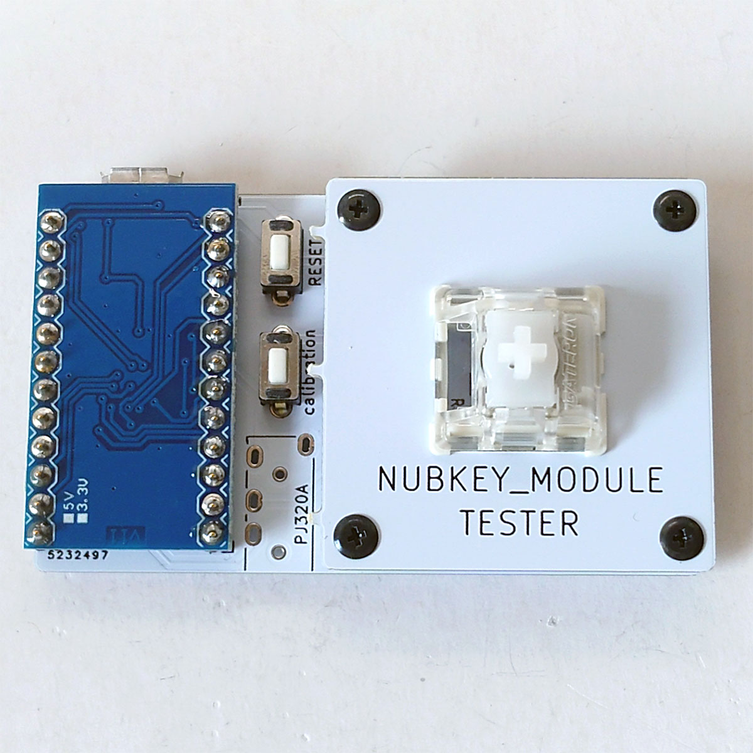
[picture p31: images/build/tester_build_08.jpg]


<br><br>

## キーキャップを付けて完成です
<br>
KS-20に好みのキーキャップを差し込んだら完成です。

<br><br>

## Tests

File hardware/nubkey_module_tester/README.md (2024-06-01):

# NUBKEY_MODULE TESTER
nubkey_module をテストする基板です。
<br><br>

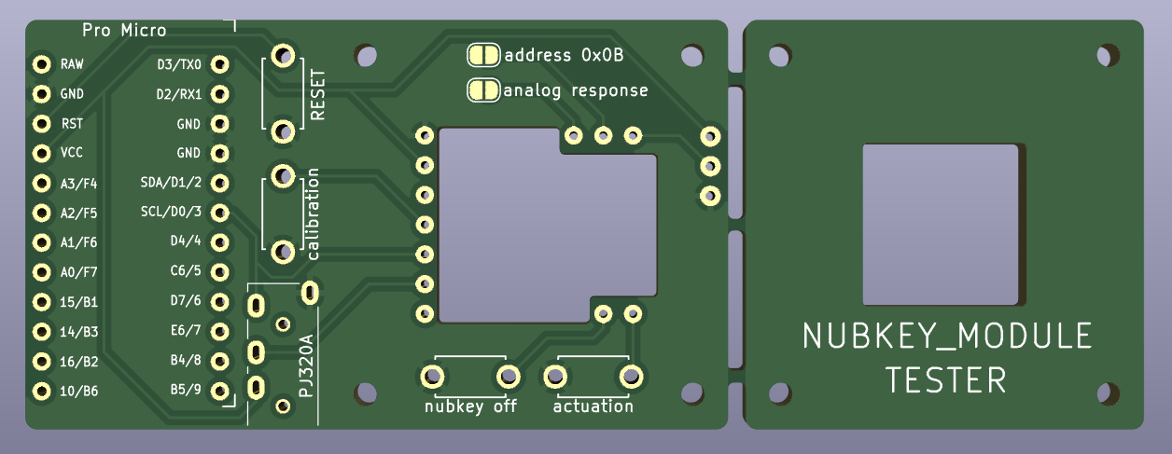
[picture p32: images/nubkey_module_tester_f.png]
pcb


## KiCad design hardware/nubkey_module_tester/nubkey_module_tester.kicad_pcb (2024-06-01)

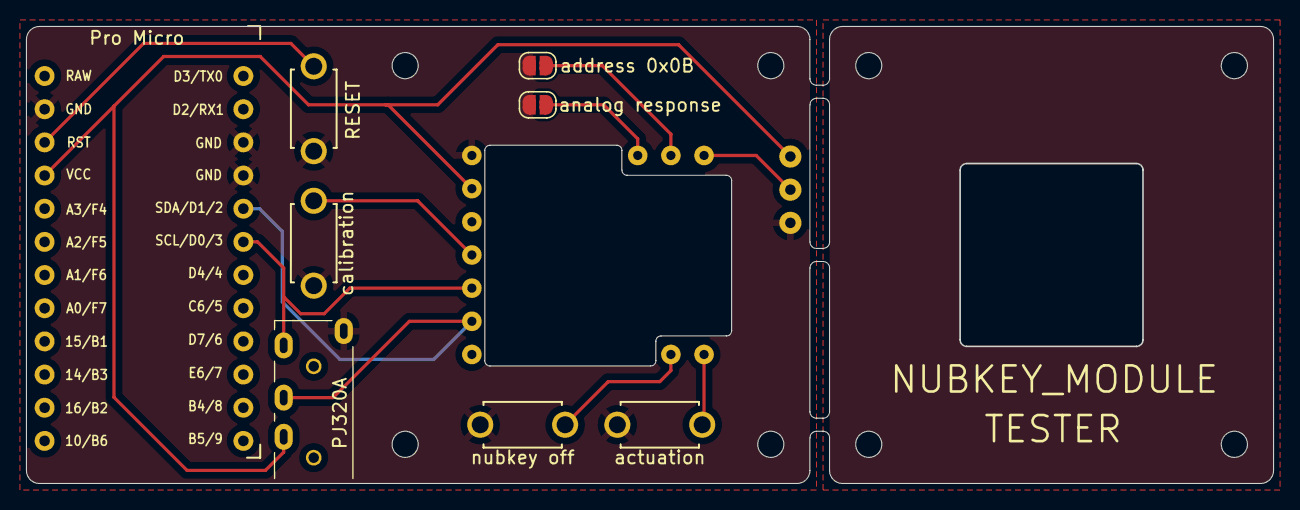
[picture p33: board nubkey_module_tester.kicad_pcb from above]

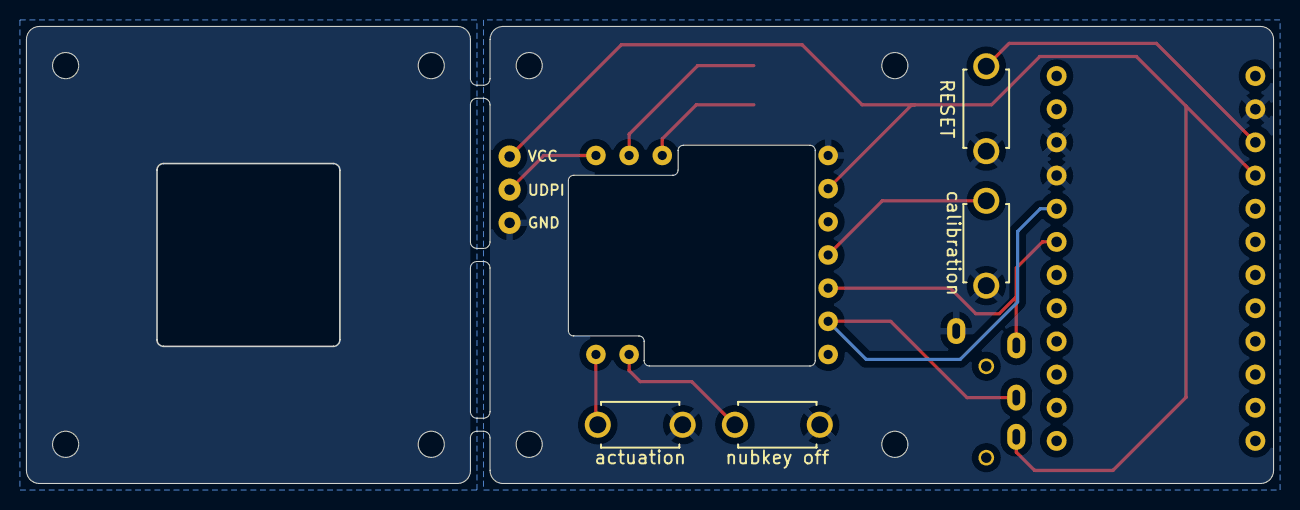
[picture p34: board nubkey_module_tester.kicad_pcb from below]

Board: 2 copper layers, 95.5 x 35.0 mm, 11 parts (4 on the bottom side), 11 nets.

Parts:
KEY_HOLE: KEY_HOLE
PJ320A: PJ320A; CON_PJ320A
RESET_SW1: SW_Push; ResetSW
U1: ProMicro; ProMicro_v3
actuation: actuation; ResetSW
address 0x0B: SolderJumper-2_P1.3mm_Open_RoundedPad1.0x1.5mm
analog response: SolderJumper-2_P1.3mm_Open_RoundedPad1.0x1.5mm
calibration: calibration; ResetSW
nubkey off: nubkey off; ResetSW
nubkey_module: nubkey_module
writer: writer; 10pin

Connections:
ADDR: address 0x0B.1, nubkey_module.2
ANA: analog response.1, nubkey_module.3
ATCP: actuation.2, nubkey_module.12
CAL: calibration.2, nubkey_module.7
GND: PJ320A.4, RESET_SW1.1, U1.3, U1.4, U1.23, actuation.1, address 0x0B.2, analog response.2, calibration.1, nubkey off.1, nubkey_module.4, writer.3
NUBOFF: nubkey off.2, nubkey_module.11
RESET: RESET_SW1.2, U1.22
SCL: PJ320A.1, U1.6, nubkey_module.8
SDA: PJ320A.2, U1.5, nubkey_module.9
UDPI: nubkey_module.1, writer.2
VCC: PJ320A.3, U1.21, nubkey_module.5, writer.1

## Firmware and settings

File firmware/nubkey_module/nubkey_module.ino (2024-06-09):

// Nubkeyの入力をPIM447フォーマットにしてI2Cに流す

// 開発環境の作り方
// https://ameblo.jp/pta55/entry-12654450554.html

#include <Wire.h>
#include <EEPROM.h>
#include <avr/wdt.h>
#include <avr/pgmspace.h>

// nubkey_module の製品識別番号
#define NUBKEY_SELIAL_NO  0x20

// ファームウェアのバージョン
#define NUBKEY_FIRMWARE_VAR  0x01

// ATTiny424 本体のアドレス
#define I2C_SLAVE_ADD_DEF  0x0A
#define I2C_SLAVE_ADD_SUB  0x0B

// 受け取るデータのバッファサイズ
#define GET_DATA_MAX_LENGTH  24

// Nubkey速度デフォルト
#define NUB_SPEED_X_DEFAULT  800
#define NUB_SPEED_Y_DEFAULT  600

// EEPROM に保存しているNubkey用の設定
struct nub_setting {
    uint8_t i2c_addr; // 自分のI2Cアドレス
    uint8_t nubkey_off_status; // Nubkey_offにするかどうか(0=Nubkey OFF / 1=Nubkey ON / 2=ピンの情報優先)
    short key_actuation; // Nubkey_off時のアクチュエーションポイント
    short nub_start_time; // Nubkeyとしてマウス操作させるまでの時間(ミリ秒)
    short nub_start_down; // Nubkey マウス移動開始させるアクチュエーションポイント
    short nub_speed_left; // Nubkey マウス移動させる速度 左
    short nub_speed_right; // Nubkey マウス移動させる速度 右
    short nub_speed_up; // Nubkey マウス移動させる速度 上
    short nub_speed_down; // Nubkey マウス移動させる速度 下
    short rang_x; // キャリブレーション中心の X 座標
    short rang_y; // キャリブレーション中心の Y 座標
    short loop_delay; // 読み込みサイクルのdelay値(ミリ秒)
};

// 現在の I2C の自分のアドレス
uint8_t i2c_addr;

// PIM447に合わせたデータフォーマットの場合(res_type = 0)
//   uint8_t 左 / uint8_t 右 / uint8_t 上 / uint8_t 下 / uint8_t 0x80でボタン押下
// アナログ値データフォーマットの場合(res_type = 1)
//   short X座標 / short Y座標 / short 押し込み具合
uint8_t res_data[8];

// レスポンスのタイプ
uint8_t res_type;

// 受け取ったコマンド -1=なし / 0>=受け取ったコマンド
short get_cmd;

// 受け取ったデータ
uint8_t get_data[GET_DATA_MAX_LENGTH];

// EEPROMに設定しているNubkey用の設定
nub_setting  nubst;

// Nubkeyの状態
short au, ad, al, ar; // 上下左右のホールセンサの値
short nub_x, nub_y; // NubkeyのX座標,Y座標
short nub_down; // 押し込み具合

// 各設定ピンの状態
bool nubkey_off_mode; // Nubkey off ピン
bool actuation_mode; // アクチュエーションポイント設定ピン
bool calibration_mode; // キャリブレーション設定ピン
uint8_t actuation_status; // アクチュエーションモード設定フラグ(0=アクチュエーション設定 OFF / 1=アクチュエーション設定 ON / 2=ピンの情報優先)
uint8_t calibration_status; // キャリブレーションモード設定フラグ(0=キャリブレーション OFF / 1=キャリブレーション ON / 2=ピンの情報優先)

// キャリブレーション設定用変数
short nub_x_min; // 取得できる X 座標の最小値
short nub_x_max; // 取得できる X 座標の最大値
short nub_y_min; // 取得できる Y 座標の最小値
short nub_y_max; // 取得できる Y 座標の最大値

// 前回のキーダウンステータス
uint8_t key_down_last;

// キーを押し始めた時間
unsigned long key_down_start;

// アクチュエーションポイント設定モード前回のステータス
bool actuation_mode_last;

// キャリブレーション設定モード前回のステータス
bool calibration_mode_last;

// I2Cイベント
void receiveEvent(int data_len); // データを受け取った
void requestEvent(); // データ要求を受け取った

// Nubkeyの設定初期値
void nubst_reset() {
    nubst.i2c_addr = 0; // 自分のアドレス 0 が設定されている場合はI2Cのアドレスはデフォルトの0x0A(ピンの設定によっては 0x0B)になる
    nubst.nubkey_off_status = 2; // Nubkey_offにするかどうか(0=Nubkey OFF / 1=Nubkey ON / 2=ピンの情報優先)
    nubst.key_actuation = 280; // キーをONとする閾値(Nubkey OFF モードの時に使われる)
    nubst.nub_start_time = 200; // Nubkeyとしてマウス操作させるまでの時間(ミリ秒)
    nubst.nub_start_down = 360; // Nubkeyとしてマウス操作開始させるアクチュエーションポイント
    nubst.nub_speed_left = NUB_SPEED_X_DEFAULT; // Nubkey マウス移動のスピード X（数値が低い方が早い）
    nubst.nub_speed_right = NUB_SPEED_X_DEFAULT; // Nubkey マウス移動のスピード X（数値が低い方が早い）
    nubst.nub_speed_up = NUB_SPEED_Y_DEFAULT; // Nubkey マウス移動のスピード Y (Y軸のがブレ幅が少ないのでY軸の方が早く動くようにする)
    nubst.nub_speed_down = NUB_SPEED_Y_DEFAULT; // Nubkey マウス移動のスピード Y (Y軸のがブレ幅が少ないのでY軸の方が早く動くようにする)
    nubst.rang_x = 0; // キャリブレーション X 座標
    nubst.rang_y = 0; // キャリブレーション Y 座標
    nubst.loop_delay = 2; // 読み込みサイクルのdelay(ミリ秒)
}

void setup() {
    uint8_t c;

    // Nubkeyの設定初期値
    nubst_reset();

    // 初めての起動の場合EPPROMにデフォルト設定を書き込む
    c = EEPROM.read(0); // 最初の0バイト目を読み込む
    if (c != 0x3A) {
      EEPROM.write(0, 0x3A); // 初期化したよを書き込む
      EEPROM.put(1, nubst); // 初期値を書き込んでおく
    }

    // EEPROMから設定を読み込む
    EEPROM.get(1, nubst);
    
    // Nubkey で使用するホールセンサーピン初期化
    pinMode(PIN_PA4, INPUT); // 下
    pinMode(PIN_PA5, INPUT); // 左
    pinMode(PIN_PA6, INPUT); // 上
    pinMode(PIN_PA7, INPUT); // 右

    // 設定ピン初期化
    pinMode(PIN_PA1, INPUT_PULLUP); // アドレス変更ピン
    pinMode(PIN_PA2, INPUT_PULLUP); // レスポンスタイプ変更ピン
    pinMode(PIN_PA3, INPUT_PULLUP); // キャリブレーション
    pinMode(PIN_PB2, INPUT_PULLUP); // アクチュエーション設定ボタン
    pinMode(PIN_PB3, INPUT_PULLUP); // Nubキーオフモード

    // 変数初期化
    key_down_last = 0;
    actuation_mode_last = false;
    calibration_mode_last = false;
    get_cmd = -1;
    actuation_status = 2;
    calibration_status = 2;
    nub_x_min = 0; // キャリブレーション X 座標の最小値
    nub_x_max = 0; // キャリブレーション X 座標の最大値
    nub_y_min = 0; // キャリブレーション Y 座標の最小値
    nub_y_max = 0; // キャリブレーション Y 座標の最大値
    memset(res_data, 0x00, 8);
    memset(get_data, 0x00, GET_DATA_MAX_LENGTH);

    // レスポンスタイプ    0=PIM447互換 / 1=アナログ値取得モード
    res_type = (digitalRead(PIN_PA2))? 0: 1;

    // I2C のアドレス    デフォルト=0x0A / GND=0x0B
    if (nubst.i2c_addr == 0) {
      i2c_addr = (digitalRead(PIN_PA1))? I2C_SLAVE_ADD_DEF: I2C_SLAVE_ADD_SUB;
    } else {
      i2c_addr = nubst.i2c_addr;
    }

    // I2C スレーブ初期化
    Wire.begin(i2c_addr);
    Wire.onReceive(receiveEvent);
    Wire.onRequest(requestEvent);

}

// コマンドを受け取った
void receiveEvent(int data_len) {
  int i = 0;
  // 送られてきたデータの取得
  while (Wire.available()) {
    get_data[i] = Wire.read();
    i++;
    if (GET_DATA_MAX_LENGTH <= i) break;
  }
  // バッファを上回るデータが渡されていたら空読み
  while (Wire.available()) Wire.read();
  // 受け取ったコマンドがあればコマンドを取得
  get_cmd = (i > 0)? get_data[0]: -1;
}

// I2Cデータ要求を受け取った時の処理
void requestEvent() {
  short c, d, e, f;

  if (get_cmd == 0x40) {
    // アドレス設定
    nubst.i2c_addr = get_data[1];
    // EEPROMに保存
    EEPROM.put(1, nubst);
    // コマンドをエコー
    Wire.write(get_cmd);
    // 60ミリ秒後に再起動
    wdt_enable(WDTO_60MS);

  } else if (get_cmd == 0x41) {
    // 設定情報取得コマンドを受け取った場合は設定情報を返す
    Wire.write(get_cmd); // コマンドをエコー
    Wire.write(nubst.i2c_addr & 0xFF);
    Wire.write(nubst.nubkey_off_status & 0xFF);
    Wire.write((nubst.key_actuation >> 8) & 0xFF);
    Wire.write(nubst.key_actuation & 0xFF);
    Wire.write((nubst.nub_start_time >> 8) & 0xFF);
    Wire.write(nubst.nub_start_time & 0xFF);
    Wire.write((nubst.nub_start_down >> 8) & 0xFF);
    Wire.write(nubst.nub_start_down & 0xFF);
    Wire.write((nubst.nub_speed_left >> 8) & 0xFF);
    Wire.write(nubst.nub_speed_left & 0xFF);
    Wire.write((nubst.nub_speed_right >> 8) & 0xFF);
    Wire.write(nubst.nub_speed_right & 0xFF);
    Wire.write((nubst.nub_speed_up >> 8) & 0xFF);
    Wire.write(nubst.nub_speed_up & 0xFF);
    Wire.write((nubst.nub_speed_down >> 8) & 0xFF);
    Wire.write(nubst.nub_speed_down & 0xFF);
    Wire.write((nubst.rang_x >> 8) & 0xFF);
    Wire.write(nubst.rang_x & 0xFF);
    Wire.write((nubst.rang_y >> 8) & 0xFF);
    Wire.write(nubst.rang_y & 0xFF);
    Wire.write((nubst.loop_delay >> 8) & 0xFF);
    Wire.write(nubst.loop_delay & 0xFF);

  } else if (get_cmd == 0x42) {
    // Nubkey OFFモードの設定を更新してEEPROMに保存
    c = nubst.nubkey_off_status;
    nubst.nubkey_off_status = get_data[1];
    // 変更があればEEPROMに保存
    if (c != nubst.nubkey_off_status) EEPROM.put(1, nubst);
    EEPROM.put(1, nubst);
    // コマンドをエコー
    Wire.write(get_cmd);

  } else if (get_cmd == 0x43) {
    // アクチュエーション設定モードの設定を更新
    actuation_status = get_data[1];
    // コマンドをエコー
    Wire.write(get_cmd);

  } else if (get_cmd == 0x44) {
    // キャリブレーション設定モードの設定を更新
    calibration_status = get_data[1];
    // コマンドをエコー
    Wire.write(get_cmd);

  } else if (get_cmd == 0x45) {
    // アクチュエーションポイント設定を更新してEEPROMに保存
    c = nubst.key_actuation;
    nubst.key_actuation = (get_data[1] << 8) | get_data[2];
    // 変更があればEEPROMに保存
    if (c != nubst.key_actuation) EEPROM.put(1, nubst);
    EEPROM.put(1, nubst);
    // コマンドをエコー
    Wire.write(get_cmd);

  } else if (get_cmd == 0x46) {
    // Nubkeyとしてマウス操作させるまでの時間を更新してEEPROMに保存
    c = nubst.nub_start_time;
    nubst.nub_start_time = (get_data[1] << 8) | get_data[2];
    // 変更があればEEPROMに保存
    if (c != nubst.nub_start_time) EEPROM.put(1, nubst);
    // コマンドをエコー
    Wire.write(get_cmd);

  } else if (get_cmd == 0x47) {
    // Nubkey 動かし始める高さを変更してEEPROMに保存
    c = nubst.nub_start_down;
    nubst.nub_start_down = (get_data[1] << 8) | get_data[2];
    // 変更があればEEPROMに保存
    if (c != nubst.nub_start_down) EEPROM.put(1, nubst);
    // コマンドをエコー
    Wire.write(get_cmd);

  } else if (get_cmd == 0x48) {
    // Nubkey マウス移動のスピードを更新してEEPROMに保存
    c = nubst.nub_speed_left;
    d = nubst.nub_speed_right;
    e = nubst.nub_speed_up;
    f = nubst.nub_speed_down;
    nubst.nub_speed_left = (get_data[1] << 8) | get_data[2];
    nubst.nub_speed_right = (get_data[3] << 8) | get_data[4];
    nubst.nub_speed_up = (get_data[5] << 8) | get_data[6];
    nubst.nub_speed_down = (get_data[7] << 8) | get_data[8];
    // 変更があればEEPROMに保存
    if (c != nubst.nub_speed_left || 
        d != nubst.nub_speed_right || 
        e != nubst.nub_speed_up || 
        f != nubst.nub_speed_down) EEPROM.put(1, nubst);
    // コマンドをエコー
    Wire.write(get_cmd);

  } else if (get_cmd == 0x49) {
    // Nubkey 読み込みサイクルのdelay値を変更してEEPROMに保存
    c = nubst.loop_delay;
    nubst.loop_delay = (get_data[1] << 8) | get_data[2];
    // 変更があればEEPROMに保存
    if (c != nubst.loop_delay) EEPROM.put(1, nubst);
    // コマンドをエコー
    Wire.write(get_cmd);

  } else if (get_cmd == 0x4A) {
    // 設定をすべてリセット
    nubst_reset();
    // EEPROMに保存
    EEPROM.put(1, nubst);
    // コマンドをエコー
    Wire.write(get_cmd);
    // 60ミリ秒後に再起動
    wdt_enable(WDTO_60MS);

  } else if (get_cmd == 0x50) {
    // アナログ値要求
    Wire.write(get_cmd);
    Wire.write((nub_x >> 8) & 0xFF);
    Wire.write(nub_x & 0xFF);
    Wire.write((nub_y >> 8) & 0xFF);
    Wire.write(nub_y & 0xFF);
    Wire.write((nub_down >> 8) & 0xFF);
    Wire.write(nub_down & 0xFF);

  } else if (get_cmd == 0x51) {
    // アナログ値要求上下左右の順番
    Wire.write(get_cmd);
    Wire.write((au >> 8) & 0xFF);
    Wire.write(au & 0xFF);
    Wire.write((ad >> 8) & 0xFF);
    Wire.write(ad & 0xFF);
    Wire.write((al >> 8) & 0xFF);
    Wire.write(al & 0xFF);
    Wire.write((ar >> 8) & 0xFF);
    Wire.write(ar & 0xFF);

  } else if (get_cmd == 0x60) {
    // コマンド 0x60 を受け取った場合は自分のアドレスと nubkey_module と判定するための番号を返す
    Wire.write(get_cmd);
    Wire.write(i2c_addr);
    Wire.write(NUBKEY_SELIAL_NO);
    Wire.write(NUBKEY_FIRMWARE_VAR);

  } else if (res_type == 1) {
    // アナログ値を返す short X / short Y / short 押し込み の6byte
    Wire.write(res_data, 6);

  } else {
    // デフォルトではPIM447フォーマット 5byte
    Wire.write(res_data, 5);
    // キーダウンは一度送信したら終わり
    if (!nubkey_off_mode) res_data[4] = 0x00;
  }
  // 呼ばれたコマンドをリセット
  get_cmd = -1;
}


void loop() {
  short mx, my;
  unsigned long t, n, p;

  // Nubkeyオフモードかピンの状態を取得
  if ((nubst.nubkey_off_status == 2 && !digitalRead(PIN_PB3)) || nubst.nubkey_off_status == 1) {
    nubkey_off_mode = true;
  } else {
    nubkey_off_mode = false;
  }

  // アクチュエーションポイント設定モードかピンの状態を取得
  if ((actuation_status == 2 && !digitalRead(PIN_PB2)) || actuation_status == 1) {
    actuation_mode = true;
  } else {
    actuation_mode = false;
  }

  // キャリブレーション設定モードかピンの状態を取得
  if ((calibration_status == 2 && !digitalRead(PIN_PA3)) || calibration_status == 1) {
    calibration_mode = true;
  } else {
    calibration_mode = false;
  }

  // Nubkey の値取得
  au = analogRead(PIN_PA6); // 上
  ad = analogRead(PIN_PA4); // 下
  ar = analogRead(PIN_PA7); // 右
  al = analogRead(PIN_PA5); // 左
  nub_x = al - ar;
  nub_y = au - ad;
  nub_down = ((au + ad + ar + al) / 4);

  if (actuation_mode) {
    // アクチュエーションポイント設定モード開始
    actuation_mode_last = true;

  } else if (!actuation_mode && actuation_mode_last) {
    // アクチュエーションポイント設定モード 終了時
    actuation_mode_last = false;
    // 今のキーの高さをアクチュエーションポイントに設定
    nubst.key_actuation = nub_down;
    // EEPROMに保存
    EEPROM.put(1, nubst);

  } else if (calibration_mode) {
    // キャリブレーション設定モード 開始時
    if (calibration_mode_last == false) {
      // キャリブレーション設定開始時に値をリセット
      nub_x_min = nub_x_max = nub_y_min = nub_y_max = 0;
    }
    calibration_mode_last = true;
    // 現在のXYを設定バッファに書き込み
    if (nub_x_min > nub_x) nub_x_min = nub_x;
    if (nub_x_max < nub_x) nub_x_max = nub_x;
    if (nub_y_min > nub_y) nub_y_min = nub_y;
    if (nub_y_max < nub_y) nub_y_max = nub_y;

  } else if (!calibration_mode && calibration_mode_last) {
    // キャリブレーション設定モード 終了時
    calibration_mode_last = false;
    // ふり幅が40以上の場合のみ設定変更(40以下は触られていないとする)
    mx = nub_x_max - nub_x_min;
    my = nub_y_max - nub_y_min;
    if (mx > 40 && my > 40) {
      nubst.rang_x = nub_x_min + (mx / 2);
      nubst.rang_y = nub_y_min + (my / 2);
      // EEPROMに保存
      EEPROM.put(1, nubst);
    }

  } else if (res_type == 1) {
    // レスポンスタイプ アナログ値 6byte
    // short X / short Y / short 押し込み
    res_data[0] = ((nub_x >> 8) & 0xFF);
    res_data[1] = (nub_x & 0xFF);
    res_data[2] = ((nub_y >> 8) & 0xFF);
    res_data[3] = (nub_y & 0xFF);
    res_data[4] = ((nub_down >> 8) & 0xFF);
    res_data[5] = (nub_down & 0xFF);

  } else {
    // 【デフォルト】
    // レスポンスタイプ PIM447フォーマット 5byte
    // uint8_t 左 / uint8_t 右 / uint8_t 上 / uint8_t 下 / uint8_t 0x80でボタン押下

    if (nubkey_off_mode) {
      // Nubkey オフモードの場合はスイッチのON/OFFのみ返す
      memset(res_data, 0x00, 4); // 上下左右を0クリア
      res_data[4] = (nub_down < nubst.key_actuation)? 0x80 : 0x00; // ボタンの情報を渡す

    } else {
      // Nubkeyの動作
      n = millis(); // 今の時間
      memset(res_data, 0x00, 4); // 上下左右を0クリア
      if (nub_down < nubst.nub_start_down) {
        if (key_down_last == 0) {
          // キー押し始め最初の処理
          key_down_last = 1;
          key_down_start = millis();
        } else {
          // キー押し続けられてる
          // どれくらい押されていたか計算
          t = n - key_down_start;
          // Nubkey開始時間より長く押されていたらマウス移動
          if (t > (unsigned long)nubst.nub_start_time) {
            mx = nub_x - nubst.rang_x; // キャリブレーションの位置を反映
            my = nub_y - nubst.rang_y; // キャリブレーションの位置を反映
            p = (nubst.nub_start_down - nub_down) / 4; // 押し込み具合取得
            // noInterrupts(); // 割り込み禁止 開始
            if (mx < 0) {
              res_data[0] = (int)(abs(mx) * p / nubst.nub_speed_left) & 0xFF;
            } else {
              res_data[1] = (int)(abs(mx) * p / nubst.nub_speed_right) & 0xFF;
            }
            if (my < 0) {
              res_data[2] = (int)(abs(my) * p / nubst.nub_speed_up) & 0xFF;
            } else {
              res_data[3] = (int)(abs(my) * p / nubst.nub_speed_down) & 0xFF;
            }
            // interrupts(); // 割り込み禁止 解除
          }
        }
      } else if (key_down_last == 1) {
          // キー離された
          key_down_last = 0;
          // どれくらい押されていたか計算
          t = n - key_down_start;
          // Nubkey開始前に離されたならばKeyダウンを送信
          if (t < (unsigned long)nubst.nub_start_time) res_data[4] = 0x80;

      }
    }
  }

  delay(nubst.loop_delay);
}
